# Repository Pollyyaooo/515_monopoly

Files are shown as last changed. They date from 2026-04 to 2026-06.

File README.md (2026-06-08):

# Smart Monopoly

A smart Monopoly system that automatically tracks board state and enforces rules, so players can focus on strategy and fun.

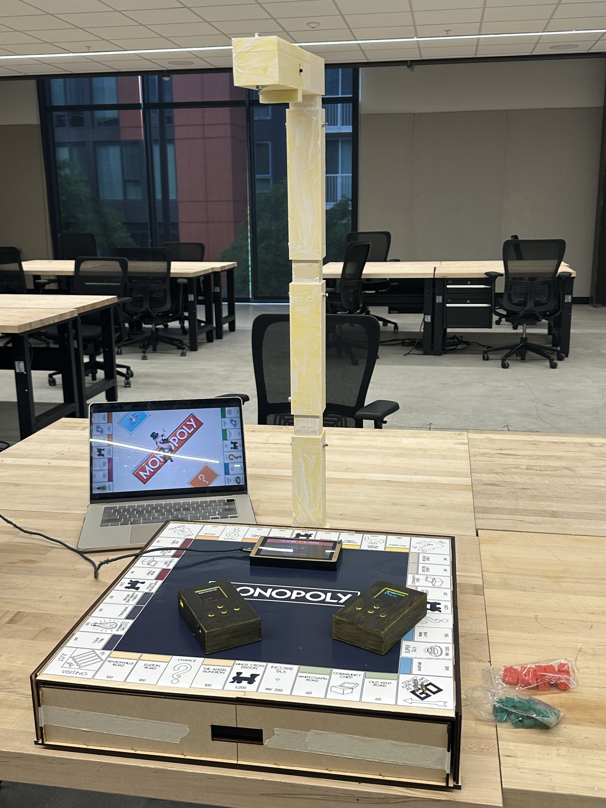
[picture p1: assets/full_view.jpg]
Full View

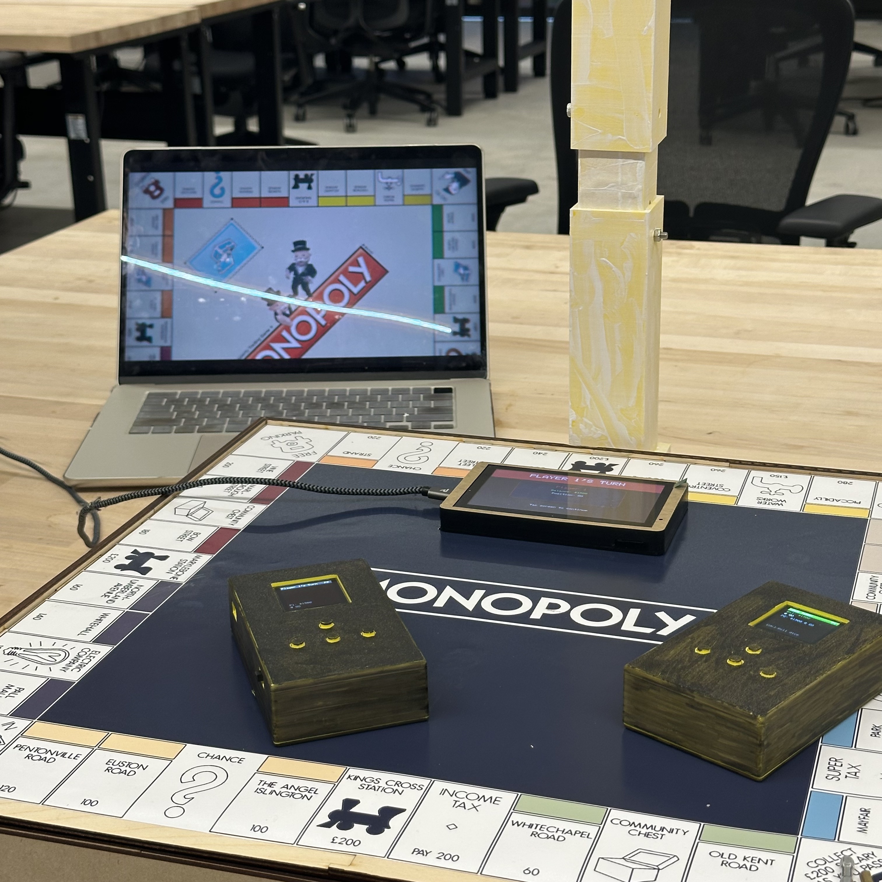
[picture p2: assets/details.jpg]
Details


## Demo Videos

| Scenario | Link |
|---|---|
| Vision detection — green house | [Watch](https://drive.google.com/file/d/1YYkAQqQGW3G5yaRUnQ6ajyW9RlyFcLrm/view?usp=drive_link) |
| Vision detection — red hotel | [Watch](https://drive.google.com/file/d/1fPO76GP8kFQUbU6NWimg8kV7IUoyudl7/view?usp=drive_link) |
| Auction | [Watch](https://drive.google.com/file/d/1G2KbDcnRxIF2fS2yyap2P3zmI8cTID51/view?usp=drive_link) |
| NFC payment | [Watch](https://drive.google.com/file/d/1PzwGUXprhIAtn__mJcu651hlFBT1dVyA/view?usp=drive_link) |

## System Overview

The system consists of three main components:

- **Vision subsystem** — Grove Vision AI V2 detects house/hotel placement on the board. An ESP32-C3 processes the raw coordinates into property-level data and transmits it to the central bank via ESP-NOW.
- **Central bank** — CrowPanel ESP32 5" manages all public game logic (dice rolls, chance/community cards, auctions, jail) and syncs state to both player devices via BLE. It also receives vision data and alerts players if houses are placed incorrectly.
- **Player devices (×2)** — Each device (XIAO ESP32-S3) has an OLED display, 4 buttons, and an NFC reader. Players use buttons to interact with the game and tap devices together for rent payments and auctions.

## Repository Structure

```
515_monopoly/
├── README.md
├── assets/
│   ├── full_view.jpg
│   └── details.jpg
├── software/
│   ├── README.md               # Code running instructions
│   ├── central_bank/           # CrowPanel ESP32 game logic & display
│   ├── player_card/            # XIAO ESP32-S3 player device firmware
│   ├── vision/                 # Grove Vision AI V2 + ESP32-C3 (ESP-NOW sender)
│   ├── central_display_test/   # Display UI testing
│   └── player_device_test/     # Player device testing
├── hardware/
│   ├── playbox+vision.f3z      # Fusion 360 enclosure & camera mount
│   ├── playbox_lasercut/       # SVG files for laser cutting
│   ├── player_card.f3z         # Fusion 360 player card enclosure
│   ├── player_card_pcb/        # PCB design files
│   ├── player_card_model/      # Player card 3D model files
│   └── vision_archi/           # Vision module hardware files
├── docs/
│   ├── milestone1.pdf
│   ├── milestone2.pdf
│   └── milestone3.pdf
└── test/                       # Early-stage hardware experiments (abandoned)
    ├── RFID test/
    ├── Hall Effect test/
    └── FSR test/
```

## Hardware

| Component | Role |
|---|---|
| Grove Vision AI V2 | House / hotel detection |
| ESP32-C3 | Coordinate processing & ESP-NOW transmission |
| CrowPanel ESP32 5" | Central bank — game logic & public display |
| XIAO ESP32-S3 (×2) | Player devices |
| OLED SSD1351 (×2) | Player display |
| NFC reader (×2) | Rent payment between players |

## Communication

| Link | Protocol |
|---|---|
| Grove Vision AI V2 → ESP32-C3 | UART |
| ESP32-C3 → CrowPanel | ESP-NOW |
| CrowPanel ↔ Player devices | BLE |
| Player device ↔ Player device | NFC |

## Team

- **Sienna** — All software (except vision model training)
- **Polly** — All hardware (enclosure, PCB, player card), vision model training & grid calibration

## Legacy Test Code

The `test/` folder contains early-stage hardware experiments (RFID, Hall Effect, FSR) that were explored during Milestone 1 but later abandoned in favour of the vision-based detection approach.

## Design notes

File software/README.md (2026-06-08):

# Monopoly Final — Smart Board Game System

A 2-player digital Monopoly system built with ESP32-S3 microcontrollers, featuring a central bank display and handheld player devices communicating over BLE.

## System Architecture

```
┌─────────────────────────┐       BLE        ┌─────────────────────────┐
│   Central Bank Display  │◄────────────────►│   Player Card (P1)      │
│   CrowPanel 5" 800×480  │                  │   XIAO ESP32S3          │
│   ESP32-S3 (game master)│       BLE        │   SSD1351 128×128 OLED  │
│                         │◄────────────────►│   PN532 NFC + 5 buttons │
└─────────────────────────┘                  ├─────────────────────────┤
                                             │   Player Card (P2)      │
                                             │   (same hardware)       │
                                             └─────────────────────────┘
```

## Hardware

| Component | Central Bank | Player Card |
|---|---|---|
| MCU | ESP32-S3 (CrowPanel 5") | Seeed XIAO ESP32S3 |
| Display | 5" IPS 800×480 (RGB parallel, LovyanGFX) | SSD1351 128×128 color OLED (SPI) |
| Input | Touchscreen (GT911) | 5 buttons (OK, LEFT, RIGHT, UP, DOWN) |
| NFC | — | PN532 (I2C) |
| Communication | BLE server (NimBLE) | BLE client (NimBLE) |

## Folder Structure

```
monopoly_final/
├── central_bank/          # Central bank display (PlatformIO project)
│   ├── platformio.ini
│   └── src/main.cpp       # Game master: state machine, dice, BLE server, UI
├── player_card/           # Player handheld device (PlatformIO project)
│   ├── platformio.ini     # Separate build envs for P1 and P2
│   └── src/main.cpp       # BLE client, OLED UI, NFC reader, button input
└── README.md
```

## Features

- **Full Monopoly rules**: 40-square UK board, property buying, rent, tax, Chance/Community Chest, jail, auctions
- **BLE communication**: Central bank acts as BLE server; player devices connect as clients
- **Dice rolling**: Dice animation on the central display, results broadcast to players
- **Property auctions**: When a player declines to buy, an auction starts with countdown timer
- **NFC payment**: Player-to-player rent payment confirmed via NFC tag tap
- **Ownership tracking**: Central bank tracks all property ownership; players can view their properties
- **Bankruptcy detection**: Automatic game-over when a player goes bankrupt

## BLE Protocol

- **Service UUID**: `0000AA01-0000-1000-8000-00805F9B34FB`
- **Notify characteristic** (central → players): `0000BB01-...`
- **Write characteristic** (players → central): `0000BB02-...`

Key messages:

| Direction | Message | Description |
|---|---|---|
| Central → Player | `TURN:{n}` | Player n's turn |
| Central → Player | `DICE:{sum}` | Dice result |
| Central → Player | `ACT:BUY:{name}:{price}` | Purchase option |
| Central → Player | `ACT:RENT:{amt}:{owner}` | Pay rent |
| Central → Player | `STATE:{p1pos}:{p1bal}:{p2pos}:{p2bal}` | Full state sync |
| Player → Central | `P{n}:ROLL` | Request dice roll |
| Player → Central | `P{n}:BUY` / `P{n}:SKIP` | Buy or skip property |

## Building & Flashing

Requires [PlatformIO](https://platformio.org/).

### Central Bank Display

```bash
cd central_bank
pio run -t upload
pio device monitor
```

### Player Cards

Flash Player 1:
```bash
cd player_card
pio run -e xiao_esp32s3_p1 -t upload
```

Flash Player 2:
```bash
cd player_card
pio run -e xiao_esp32s3_p2 -t upload
```

The player number is set via `-DPLAYER_NUM=1` or `-DPLAYER_NUM=2` in the build flags.

## Wiring (Player Card)

| OLED Pin | XIAO Pin | GPIO |
|---|---|---|
| DIN/MOSI | D10 | GPIO9 |
| CLK/SCK | D8 | GPIO7 |
| CS | D1 | GPIO1 |
| DC | D2 | GPIO2 |
| RST | D3 | GPIO3 |

PN532 NFC is connected via I2C (default SDA/SCL pins on XIAO ESP32S3).

## Team

- **Sienna** — board sensing, central display, game logic
- **Polly** — player device, BLE integration

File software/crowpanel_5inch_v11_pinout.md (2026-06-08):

# CrowPanel Advance 5.0" HMI ESP32-S3 — DIS02050A V1.1 引脚速查

> 来源：官方 GitHub `factory_sourcecode/V1.1/HMI-bigInch5/LovyanGFX_Driver.h`  
> **所有引脚已从官方代码确认，可直接使用**

---

## RGB 显示接口（16-bit 并行，Bus_RGB）

| 信号 | GPIO | 说明 |
|---|---|---|
| D0  | 21  | Blue[4] MSB |
| D1  | 47  | Blue[3] |
| D2  | 48  | Blue[2] |
| D3  | 45  | Blue[1] |
| D4  | 38  | Blue[0] LSB |
| D5  | 9 | Green[5] MSB |
| D6  | 10  | Green[4] |
| D7  | 11  | Green[3] |
| D8  | 12  | Green[2] |
| D9  | 13  | Green[1] |
| D10 | 14  | Green[0] LSB |
| D11 | 7 | Red[4] MSB |
| D12 | 17  | Red[3] |
| D13 | 18  | Red[2] |
| D14 | 3 | Red[1] |
| D15 | 46  | Red[0] LSB |
| DE (henable) | **42** | Data Enable |
| VSYNC | **41** | |
| HSYNC | **40** | |
| PCLK  | **39** | 21 MHz |

### 时序参数（官方值）

```
pclk_idle_high    = 1      ← 重要！不设会花屏
hsync_polarity    = 0
hsync_front_porch = 8
hsync_pulse_width = 4
hsync_back_porch  = 8
vsync_polarity    = 0
vsync_front_porch = 8
vsync_pulse_width = 4
vsync_back_porch  = 8
freq_write        = 21000000
```

---

## 触摸控制器（GT911）

| 参数 | 值 |
|---|----|
| 芯片 | GT911 |
| I2C 地址 | **0x5D** |
| SDA | **IO15** |
| SCL | **IO16** |
| INT | -1（无）|
| RST | -1（无）|
| I2C port | I2C_NUM_0 |
| 频率 | 400 kHz |

---

## STC8H1K28（背光 + Buzzer + 音频控制）

| 参数 | 值 |
|---|----|
| I2C 地址 | **0x30** |
| I2C 总线 | 与 GT911 共用，SDA=IO15, SCL=IO16 |

### 命令表

| 命令字节 | 功能 |
|---|---|
| `0x01` | 背光控制前导（先发此，再发亮度） |
| `0x05` | 背光最亮 |
| `0x10` | 背光最暗 |
| `0x15` | **Buzzer ON** |
| `0x16` | **Buzzer OFF** |
| `0x17` | 音频 Unmute |
| `0x18` | 音频 Mute |

### 背光控制代码

```cpp
Wire.begin(15, 16);          // 初始化 I2C

// 设置亮度（先发 0x01，再发亮度值）
Wire.beginTransmission(0x30);
Wire.write(0x01);
Wire.endTransmission();
delay(5);
Wire.beginTransmission(0x30);
Wire.write(0x05);  // 最亮
Wire.endTransmission();

// Buzzer
Wire.beginTransmission(0x30);
Wire.write(0x15);  // ON
Wire.endTransmission();
delay(100);
Wire.beginTransmission(0x30);
Wire.write(0x16);  // OFF
Wire.endTransmission();
```

> ⚠️ **没有背光 GPIO** — V1.1 完全通过 I2C 控制，代码中不需要 `setBrightness()` 或任何 `Light_PWM`

---

## RTC（BM8563）

| 参数 | 值 |
|---|----|
| I2C 地址 | **0x51** |
| SDA | IO15 |
| SCL | IO16 |

> 与 GT911（0x5D）和 STC8H1K28（0x30）共用同一 I2C 总线

---

## 其他接口引脚

| 功能 | GPIO |
|---|---|
| UART0 TX | IO43 |
| UART0 RX | IO44 |
| UART1 TX | IO20 |
| UART1 RX | IO19 |
| SPK LRCLK | IO6 |
| SPK BCLK | IO5 |
| SPK SDIN | IO4 |
| MIC SD | IO20 |
| MIC WS | IO2 |
| MIC CLK | IO19 |
| SD MOSI | IO6 |
| SD MISO | IO4 |
| SD CLK | IO5 |

---

## PSRAM 启用

官方代码中启用了 PSRAM（`use_psram = 1`），platformio.ini 需要：

```ini
board_build.arduino.memory_type = qio_opi
build_flags = -DBOARD_HAS_PSRAM
```

---

## 官方 GitHub

`https://github.com/Elecrow-RD/CrowPanel-Advance-5-HMI-ESP32-S3-AI-Powered-IPS-Touch-Screen-800x480`

关键文件：`factory_sourcecode/V1.1/HMI-bigInch5/LovyanGFX_Driver.h`

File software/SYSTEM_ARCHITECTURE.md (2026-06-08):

# Monopoly Physical Game System — 系统架构文档

> **版本:** v1.0 · **日期:** 2026-05-08  
> **项目:** UW MSTI 515 · Phygital Monopoly

---

## 1. 系统总览

本系统将经典大富翁拆分为两类设备，职责清晰：

| 设备 | 硬件 | 职责 |
|---|---|---|
| **Central Display（公共屏幕）** | CrowPanel ESP32-S3 5" (DIS02050A) | 讲故事、投骰子动画、公共事件、回合广播 |
| **Player Device（玩家设备）** | Seeed XIAO ESP32S3 + SSD1351 128×128 OLED + PN532 | 个人资产、个人决策、支付确认、NFC 位置扫描 |

通信方式：**Bluetooth Low Energy (BLE)**  
拓扑：Central Display 作为 **BLE Central（Server）**，最多 4 台 Player Device 作为 **BLE Peripherals（Clients）**

```
┌──────────────────────────────────────────────────────────────────┐
│                     CrowPanel 5" (Central Display)               │
│  ESP32-S3 WROOM-1 · 800×480 Touch · Buzzer · Speaker            │
│                                                                  │
│  ┌─────────────┐  ┌──────────────┐  ┌────────────────────────┐  │
│  │ Game Engine │  │  BLE Central │  │   Display / Animation  │  │
│  │  (Master)   │←→│  (4 slots)   │  │  Dice · Cards · Events │  │
│  └─────────────┘  └──────┬───────┘  └────────────────────────┘  │
│                           │ BLE                                   │
└───────────────────────────┼──────────────────────────────────────┘
                            │
         ┌──────────────────┼──────────────────┐
         │                  │                  │
  ┌──────┴──────┐   ┌──────┴──────┐   ┌──────┴──────┐
  │  Player 1   │   │  Player 2   │   │  Player 3/4 │
  │ XIAO ESP32S3│   │ XIAO ESP32S3│   │ XIAO ESP32S3│
  │ OLED + NFC  │   │ OLED + NFC  │   │ OLED + NFC  │
  └─────────────┘   └─────────────┘   └─────────────┘
```

---

## 2. 硬件规格

### 2.1 Central Display — CrowPanel ESP32-S3 5"

| 参数 | 值 |
|---|----|
| SKU | DIS02050A V1.1 |
| MCU | ESP32-S3 WROOM-1 |
| 屏幕 | 5.0" TFT，800×480，电容触摸 |
| 接口 | UART0/1-IN/OUT · I2C-OUT · USB-5V-IN |
| 音频 | 板载 Buzzer + Speaker (SPK 接口) |
| 存储 | TF Card slot |
| 电源 | USB-5V-IN / BAT |
| BLE | ESP32-S3 内置 BLE 5.0 |

**推荐开发框架：** Arduino (PlatformIO) + LVGL 8.x（UI 动画）

### 2.2 Player Device — Seeed XIAO ESP32S3

| 参数 | 值 |
|---|----|
| MCU | ESP32-S3 |
| 显示 | SSD1351 128×128 RGB OLED (SPI) |
| NFC | PN532（I2C 模式） |
| 输入 | 5× 触觉按钮（UP / DOWN / LEFT / RIGHT / OK） |
| BLE | ESP32-S3 内置 BLE 5.0 |

---

## 3. BLE 通信协议

### 3.1 拓扑与连接

- Central Display 开启 **BLE Server**，广播服务 UUID。
- 每台 Player Device 启动后扫描并连接 Central，注册自己的 Player ID（0~3）。
- 最多同时 4 条 BLE 连接。

### 3.2 GATT 服务定义

```
Service UUID: 0xAA01  (Monopoly Game Service)
│
├── Characteristic 0xBB01  [NOTIFY | WRITE]
│   名称: Game Event (Central → Players)
│   方向: Central 广播给所有 Player
│   载荷: JSON 或固定字节包（见 3.3）
│
├── Characteristic 0xBB02  [WRITE]
│   名称: Player Action (Player → Central)
│   方向: Player Device 上报动作
│   载荷: 固定字节包
│
└── Characteristic 0xBB03  [READ]
    名称: Game State Snapshot
    方向: Player 可随时读取完整游戏状态
    载荷: 压缩状态包
```

### 3.3 消息包格式

#### Central → Player（Game Event Packet）

```
[1B] msg_type  | 消息类型（见下表）
[1B] player_id | 目标 player（0xFF = 广播全体）
[2B] payload_a | 主要参数
[2B] payload_b | 次要参数
[1B] checksum  | XOR 校验
```

| msg_type | 含义 | payload_a | payload_b |
|---|---|---|---|
| `0x01` | YOUR_TURN | player_id | — |
| `0x02` | DICE_RESULT | die1 (1-6) | die2 (1-6) |
| `0x03` | MOVE_TO | square_index | — |
| `0x04` | CHANCE_CARD | card_id | — |
| `0x05` | COMMUNITY_CARD | card_id | — |
| `0x06` | PAY_REQUEST | amount (uint16) | recipient_id |
| `0x07` | COLLECT | amount (uint16) | source (0=bank) |
| `0x08` | GO_TO_JAIL | — | — |
| `0x09` | GAME_OVER | winner_id | — |
| `0x0A` | SYNC_BALANCE | balance (uint16) | — |
| `0x0B` | PROPERTY_UPDATE | square_index | owner_id |

#### Player → Central（Player Action Packet）

```
[1B] msg_type  | 动作类型
[1B] player_id | 发送方
[2B] payload_a |
[2B] payload_b |
[1B] checksum  |
```

| msg_type | 含义 | payload_a | payload_b |
|---|---|---|---|
| `0x81` | ROLL_DICE | — | — |
| `0x82` | BUY_PROPERTY | square_index | — |
| `0x83` | PAY_CONFIRM | amount | recipient_id |
| `0x84` | PAY_REJECT | — | — |
| `0x85` | USE_CARD | card_id | — |
| `0x86` | NFC_SCANNED | square_index | — |
| `0x87` | END_TURN | — | — |
| `0x88` | MORTGAGE | square_index | — |

---

## 4. Game Engine（运行在 Central Display）

Central Display 是游戏的**唯一权威状态机**，所有 Player Device 只展示结果、等待指令。

### 4.1 状态机

```
WAITING_FOR_PLAYERS
      │ 4 players connected
      ▼
   GAME_START
      │ broadcast turn order
      ▼
┌─► PLAYER_TURN_START
│     │ broadcast YOUR_TURN → player_id
│     ▼
│   WAITING_ROLL
│     │ receive ROLL_DICE from current player
│     ▼
│   ROLLING_DICE ──── 播放骰子动画（Central屏幕）
│     │ animation done, compute result
│     │ broadcast DICE_RESULT
│     ▼
│   MOVING_PLAYER ─── 广播 MOVE_TO
│     │
│     ▼
│   RESOLVE_SQUARE ───────────────────────────────────────────────┐
│     │ SQ_PROPERTY  → 广播 PAY_REQUEST 或 BUY 选项              │
│     │ SQ_CHANCE    → 抽卡，广播 CHANCE_CARD + 执行效果         │
│     │ SQ_COMMUNITY → 抽卡，广播 COMMUNITY_CARD + 执行效果      │
│     │ SQ_TAX       → 广播 PAY_REQUEST (bank)                   │
│     │ SQ_GO_JAIL   → 广播 GO_TO_JAIL                           │
│     │ SQ_SPECIAL   → 无动作 / Collect $200                     │
│     │                                                           │
│     ▼                                                           │
│   WAITING_PLAYER_ACTION ←──────────────────────────────────────┘
│     │ receive PAY_CONFIRM / BUY / END_TURN
│     │ update GameState
│     │ broadcast SYNC_BALANCE to affected players
│     ▼
│   CHECK_BANKRUPTCY ─── 检查是否有玩家破产
│     │ if bankrupt → remove player
│     │ if 1 player left → GAME_OVER
│     ▼
└─── TURN_END ─── next player
```

### 4.2 GameState 数据结构（Central 持有）

```cpp
struct GameState {
  Player  players[4];       // 所有玩家状态
  Square  board[40];        // 完整 40 格棋盘
  int     currentTurnIdx;   // 当前回合玩家
  int     totalPlayers;     // 在线玩家数
  int     chanceDeck[16];   // Chance 牌堆
  int     communityDeck[16];// Community Chest 牌堆
  int     chanceTop;        // 当前抽牌指针
  int     communityTop;
  bool    doublesRolled;    // 是否连续骰到 doubles
  int     doublesCount;
};
```

---

## 5. Central Display — UI 模块

### 5.1 屏幕页面划分

```
┌─────────────────────────────────────────┐
│  CrowPanel 5"  800×480                  │
│                                         │
│  主要页面（全屏）：                      │
│  ┌──────────────────────────────────┐   │
│  │ IDLE / WAITING    等待玩家连接   │   │
│  ├──────────────────────────────────┤   │
│  │ DICE ROLL SCREEN  投骰子动画     │   │
│  ├──────────────────────────────────┤   │
│  │ EVENT SCREEN      公共事件通知   │   │
│  ├──────────────────────────────────┤   │
│  │ CARD DRAW         Chance/Community│  │
│  ├──────────────────────────────────┤   │
│  │ BOARD OVERVIEW    棋盘全览（可选）│  │
│  └──────────────────────────────────┘   │
└─────────────────────────────────────────┘
```

### 5.2 骰子动画（Dice Roll Screen）

- 收到 `ROLL_DICE` 请求后触发
- 播放 **随机旋转骰子精灵图动画**（LVGL `lv_animimg` 或帧循环）
- 动画时长：1.5~2 秒，渐慢停止
- 停止后显示最终骰子面值（大字，带声效 Buzzer）
- 发送 `DICE_RESULT` BLE 广播

**实现方案：**
```
TF Card 存储骰子帧图片（BMP/PNG）
→ LVGL lv_img / lv_animimg 逐帧播放
→ 结束帧 = 实际 RNG 结果
```

### 5.3 公共事件屏（Event Screen）

显示触发事件，保持 3~5 秒后自动进入下一状态：

| 事件 | 显示内容 |
|---|---|
| 回合开始 | "🎲 Alice's Turn!" + 玩家颜色背景 |
| 移动完成 | "Alice → Park Place" |
| 抽 Chance 牌 | 大字显示牌面内容 + 图标 |
| 抽 Community 牌 | 大字显示牌面内容 + 图标 |
| 支付发生 | "Alice pays Bob $50" |
| 入狱 | "🔒 Alice goes to Jail!" |
| 通过 Go | "Alice collects $200!" |
| 破产 | "Dave is bankrupt! 💸" |
| 游戏结束 | "Alice WINS! 🏆" |

### 5.4 抽卡画面（Card Draw Screen）

- 动画：卡片从牌堆飞出，翻转展示正面
- 正面显示：卡牌名称 + 描述文字 + 效果图标
- 保持显示直到触摸屏或收到 `END_TURN`

---

## 6. Player Device — UI 模块（已有基础版）

### 6.1 现有页面（保持不变）

| 页面 | 内容 |
|---|---|
| PAGE_HOME | 玩家名、余额、位置、道具/卡牌数量 |
| PAGE_ACTION | 当前格子可执行动作（买/付租金/税） |
| PAGE_PROPERTIES | 持有地产列表（含房屋图标） |
| PAGE_CARDS | 持有卡牌列表 |
| PAGE_NFC_SCAN | NFC 扫描提示 |

### 6.2 新增页面（BLE 接入后）

| 页面 | 触发时机 | 内容 |
|---|---|---|
| PAGE_WAIT_TURN | 非当前玩家 | "Bob's turn..." + 当前回合进度 |
| PAGE_PAY_CONFIRM | 收到 `PAY_REQUEST` | "Pay $50 to Bob? OK/Cancel" |
| PAGE_CARD_RECEIVED | 收到 Chance/Community 结果 | 显示抽到的牌效果 |
| PAGE_BANKRUPT | 余额 < 0 | "You are bankrupt!" |

### 6.3 BLE 接入流程（Player Device 侧）

```
setup():
  1. 扫描 BLE，连接 UUID=0xAA01 的 Central
  2. 订阅 Characteristic 0xBB01 (NOTIFY)
  3. 发送注册包：player_id = 用户选择的颜色/编号

loop():
  - 监听 BLE NOTIFY 回调 → 解析 Game Event → 更新本地状态 → 刷新 OLED
  - 处理按钮 → 构造 Player Action 包 → BLE WRITE 到 0xBB02
  - NFC 扫描 → 发送 NFC_SCANNED 包 → 等待 Central 下发 MOVE_TO
```

---

## 7. 开发分工与文件结构

```
monopoly_final/
│
├── central_display/              # CrowPanel 5" 固件
│   ├── platformio.ini
│   └── src/
│       ├── main.cpp              # setup / loop
│       ├── game_engine.h/cpp     # GameState + 状态机
│       ├── ble_central.h/cpp     # BLE Server / 4连接管理
│       ├── ui_dice.h/cpp         # 骰子动画
│       ├── ui_event.h/cpp        # 公共事件屏
│       ├── ui_card.h/cpp         # 抽卡画面
│       └── cards_data.h          # 所有 Chance / Community 牌内容
│
├── player_device/                # XIAO ESP32S3 固件（含现有代码）
│   ├── platformio.ini
│   └── src/
│       ├── main.cpp              # setup / loop（扩展现有版本）
│       ├── ble_client.h/cpp      # BLE Peripheral / NOTIFY 处理
│       ├── game_state.h/cpp      # 本地 GameState 镜像
│       ├── ui_pages.h/cpp        # 所有页面绘制（现有 + 新增）
│       └── nfc_handler.h/cpp     # PN532 扫描逻辑
│
├── shared/                       # 两端共用定义
│   └── protocol.h                # BLE UUID / 消息包结构 / 枚举
│
└── SYSTEM_ARCHITECTURE.md        # 本文档
```

---

## 8. 开发阶段规划

### Phase 1：BLE 连接基础（无游戏逻辑）
- [ ] Central：BLE Server 广播 + 接受 4 连接
- [ ] Player：BLE Client 扫描连接 + 发送心跳
- [ ] 验证：4 台设备同时连接，收发测试包

### Phase 2：骰子 + 回合广播
- [ ] Central：骰子动画（LVGL）+ RNG + 广播 DICE_RESULT
- [ ] Central：YOUR_TURN 广播 + 事件屏显示
- [ ] Player：接收 YOUR_TURN → 高亮显示 → 按 OK 发送 ROLL_DICE

### Phase 3：NFC 位置 + 格子解析
- [ ] Player：PN532 扫描 → 发送 NFC_SCANNED
- [ ] Central：接收 NFC_SCANNED → 更新 position → 广播 MOVE_TO + 解析格子事件

### Phase 4：支付 + 资产管理
- [ ] Central：PAY_REQUEST 定向发送 + 等待 PAY_CONFIRM
- [ ] Player：PAY_CONFIRM 页面 + BLE 回复
- [ ] Central：SYNC_BALANCE 广播 → Player 更新余额显示

### Phase 5：Chance / Community 牌
- [ ] Central：抽卡动画 + 牌效果执行 + 广播
- [ ] Player：接收 CARD_RECEIVED → 显示卡牌内容页面

### Phase 6：整体测试 + 音效
- [ ] CrowPanel Buzzer：骰子 / 收钱 / 入狱 音效
- [ ] 端到端完整游戏流程测试

---

## 9. 关键技术选型说明

| 决策 | 选择 | 原因 |
|---|---|---|
| 通信协议 | BLE（非 WiFi） | 无需路由器，现场部署简单；ESP32-S3 原生支持 |
| Central 为 Server | 是 | 状态权威在 Central，避免多端同步冲突 |
| UI 框架（Central）| LVGL 8.x | CrowPanel 官方支持；动画能力强（animimg、过渡效果） |
| UI 框架（Player）| Adafruit GFX | 已有稳定基础代码，资源占用低 |
| NFC → 位置映射 | Player 本地查表 + 上报 index | 减少 BLE 传输量；Central 收到 index 即可 |
| 游戏状态存储 | Central 单一权威 | Player Device 只保存本地镜像，以 Central 为准 |

---

## 10. BLE 实现参考（Arduino NimBLE）

两端均使用 **NimBLE-Arduino** 库（PlatformIO 依赖：`h2zero/NimBLE-Arduino`），资源占用比官方 ESP-IDF BLE 栈小约 50%。

```cpp
// platformio.ini 公共依赖
[env]
lib_deps =
  h2zero/NimBLE-Arduino @ ^1.4.1
  lvgl/lvgl @ ^8.3.0          ; Central only
  adafruit/Adafruit GFX Library
  adafruit/Adafruit SSD1351 library
  adafruit/Adafruit PN532     ; Player only
```

---

*文档由 Claude Code 辅助生成，基于现有 player_device_test 代码与 CrowPanel DIS02050A 硬件规格。*

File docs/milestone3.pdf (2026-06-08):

# Morden MONOPOLY

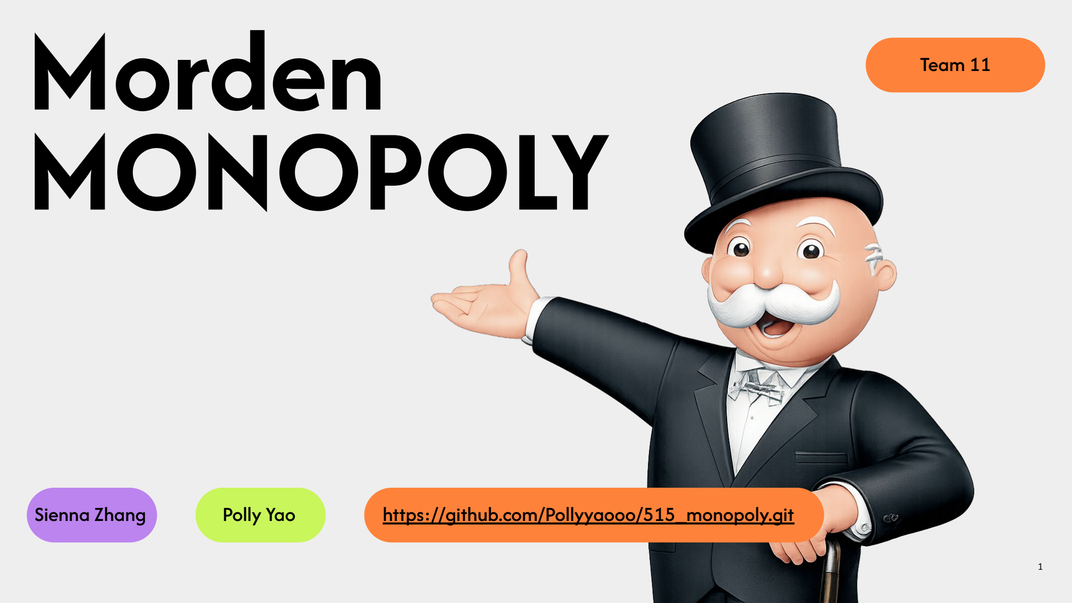
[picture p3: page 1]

## Team 11

Sienna Zhang | Polly Yao | https://github.com/Pollyyaooo/515_monopoly.git

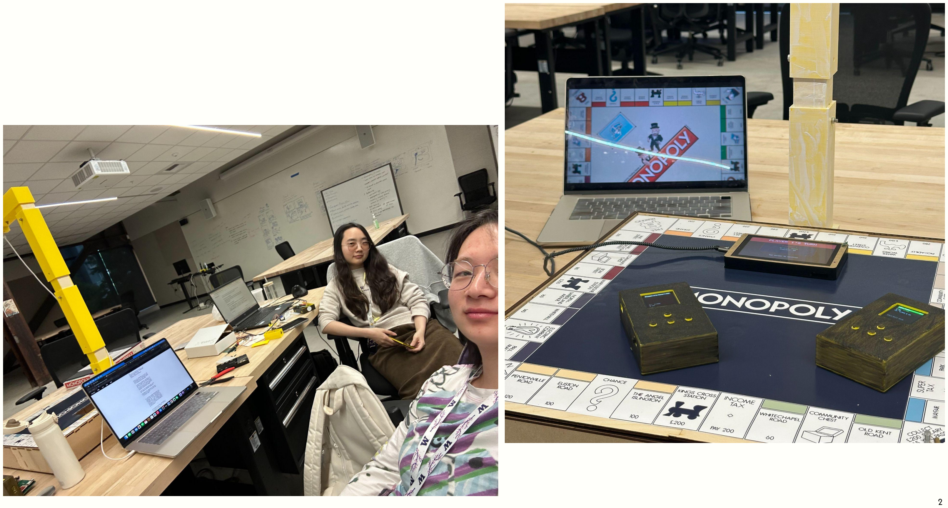
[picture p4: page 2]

“

# How might we reduce the administrative burden of tracking game state and enforcing rules in Monopoly, so that all players can focus on strategy and fun?

# Why we want…

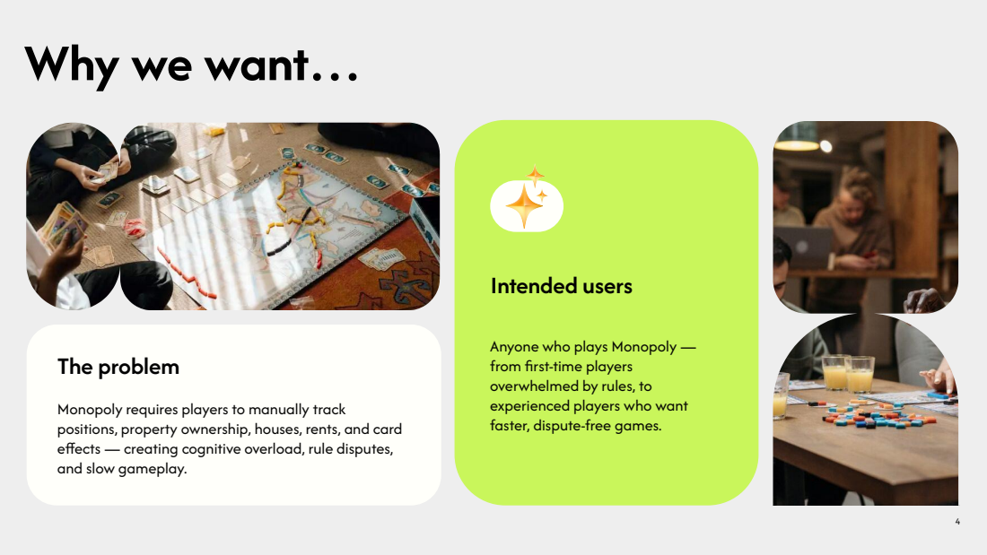
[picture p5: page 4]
Intended users; The problem

Anyone who plays Monopoly —
from first-time players
overwhelmed by rules, to
experienced players who want
faster, dispute-free games.

Monopoly requires players to manually track
positions, property ownership, houses, rents, and card
effects — creating cognitive overload, rule disputes,
and slow gameplay.

# Solution

# A smart Monopoly system that automatically tracks board state and enforces rules, so

players never have to.

# Board Intelligence

## The physical board is enhanced with sensors to automatically detect and track:

## - Player token positions (who is where) - Property ownership status - Number and color of houses built on each property

# Rules Intelligence

## Game information is processed and displayed in real time across two interfaces: - A Central Bank screen (public display) — shows card draws, rent calculations, property transactions… - Individual player devices (private display) —

shows personal balance, rent owed/collected, player-to-player transfers..

# Architecture 2

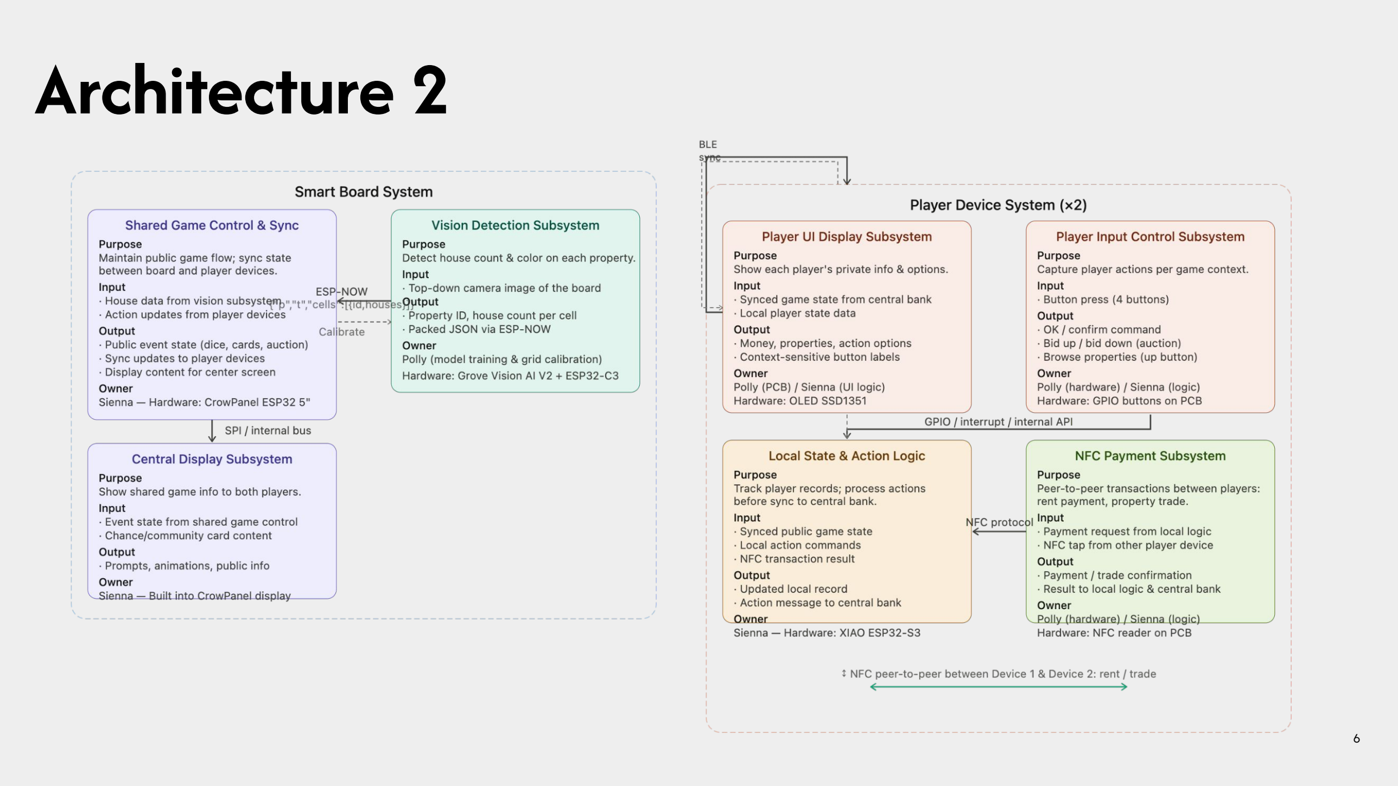
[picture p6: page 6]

# Optimization 1 - Enclosure & Camera Mount Stability

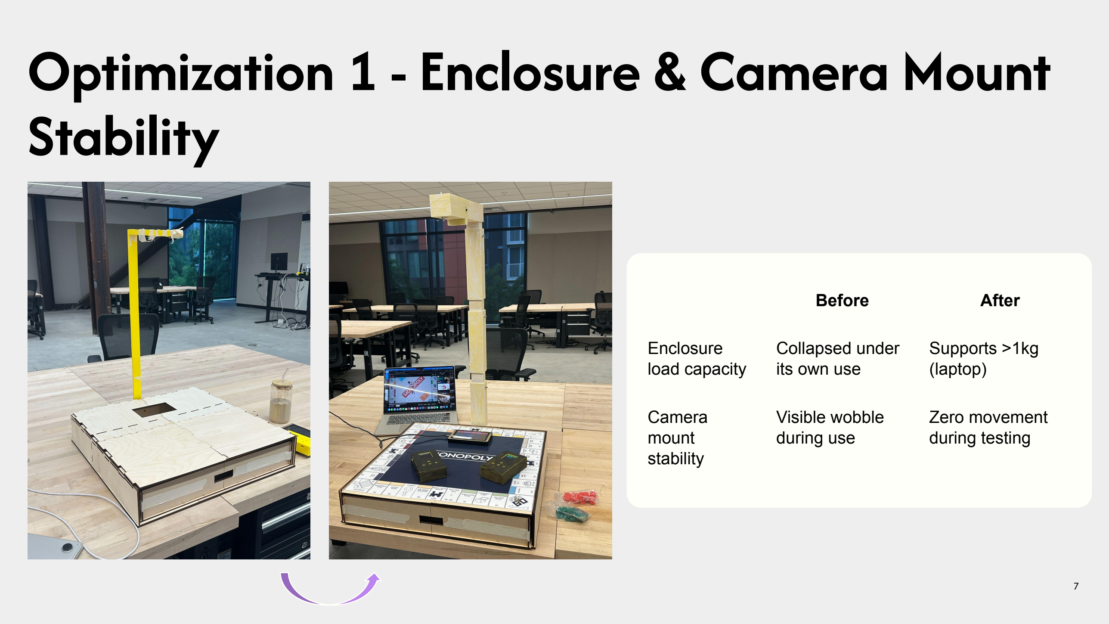
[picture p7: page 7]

Before | After

Enclosure
load capacity
Collapsed under its own use | Supports >1kg (laptop)

Camera
mount
stability
Visible wobble during use | Zero movement during testing

# Optimization 2 - Central Display UI

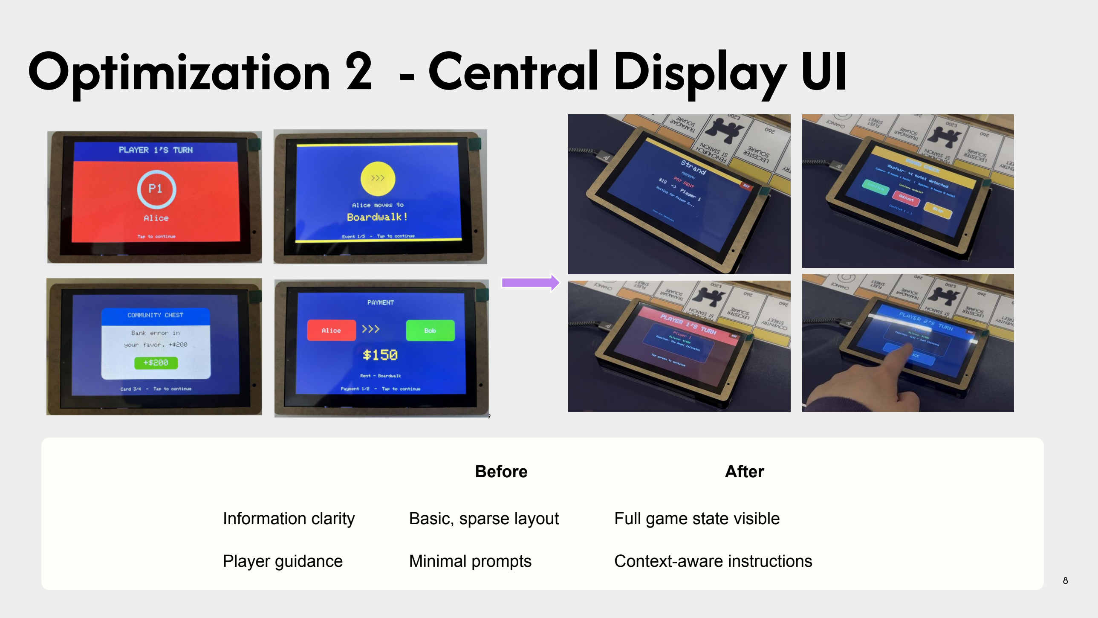
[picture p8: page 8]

| Before | After
Information clarity | Basic, sparse layout | Full game state visible
Player guidance | Minimal prompts | Context-aware instructions

# Optimization 3

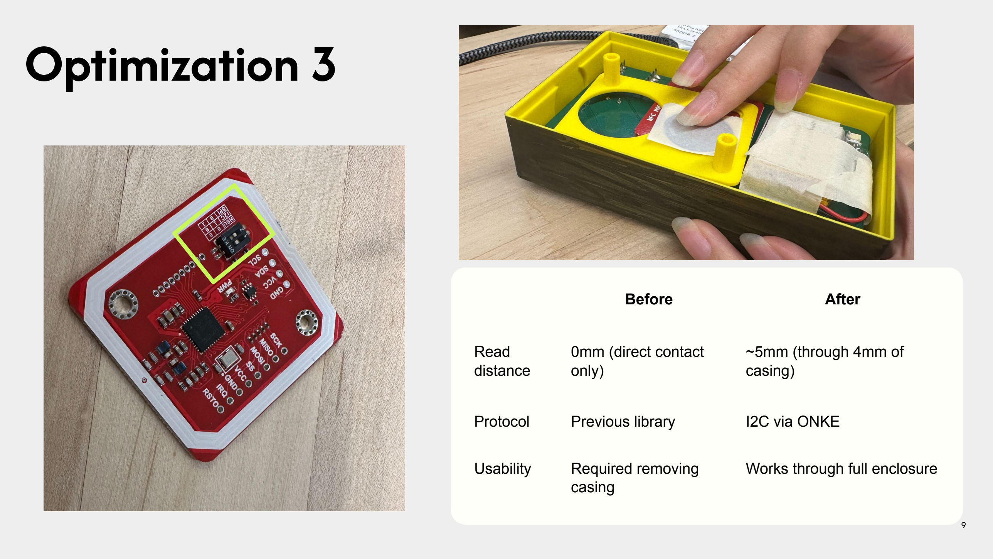
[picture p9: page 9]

Before | After

Read
distance

0mm (direct contact
only)

~5mm (through 4mm of
casing)
Protocol | Previous library | I2C via ONKE
Usability | Required removing casing | Works through full enclosure

# Readiness - NFC vs auction

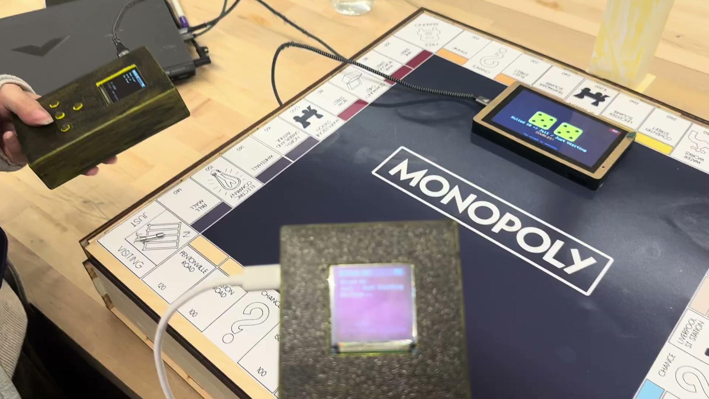
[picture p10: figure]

Condition 1: NFC-based rent payment When a player lands on an opponent's property, the system triggers a rent payment flow. The paying player taps their device to the receiving player's NFC reader to complete the transaction, with the updated balance automatically synced to the central bank.

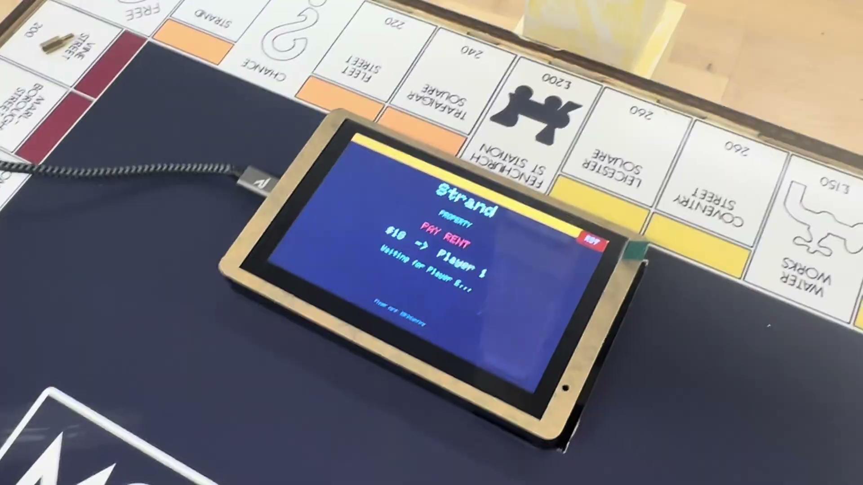
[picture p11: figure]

Condition 2: Button-based auction When a property is not purchased by the landing player, an auction is triggered on the central display. Both players use the left/right buttons on their devices to raise or lower their bids, and confirm with the center button. The highest confirmed bid wins the property.

# Readiness - house vs hotel

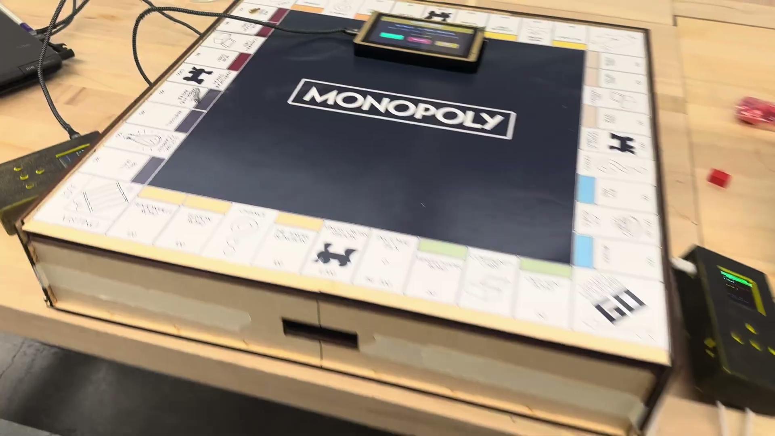
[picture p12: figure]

Condition 1: Incorrect green house placement A property is deliberately set up with an incorrect number of green houses on the board. The camera subsystem detects the mismatch between the physical board state and the expected game state, triggering a visual alert on the central display to prompt the players to correct the placement.

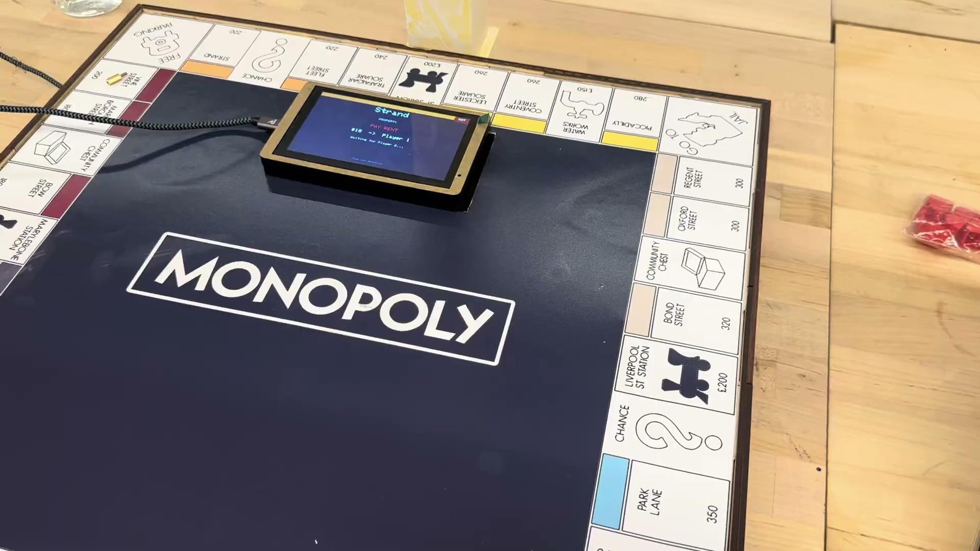
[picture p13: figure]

Condition 2: Incorrect red hotel placement The same detection flow is tested with red hotels, which differ in both color and shape from green houses. The camera subsystem successfully identifies the incorrect number of hotels and triggers a corresponding alert on the central display, demonstrating that the vision model generalizes across both building types.

# Budget update

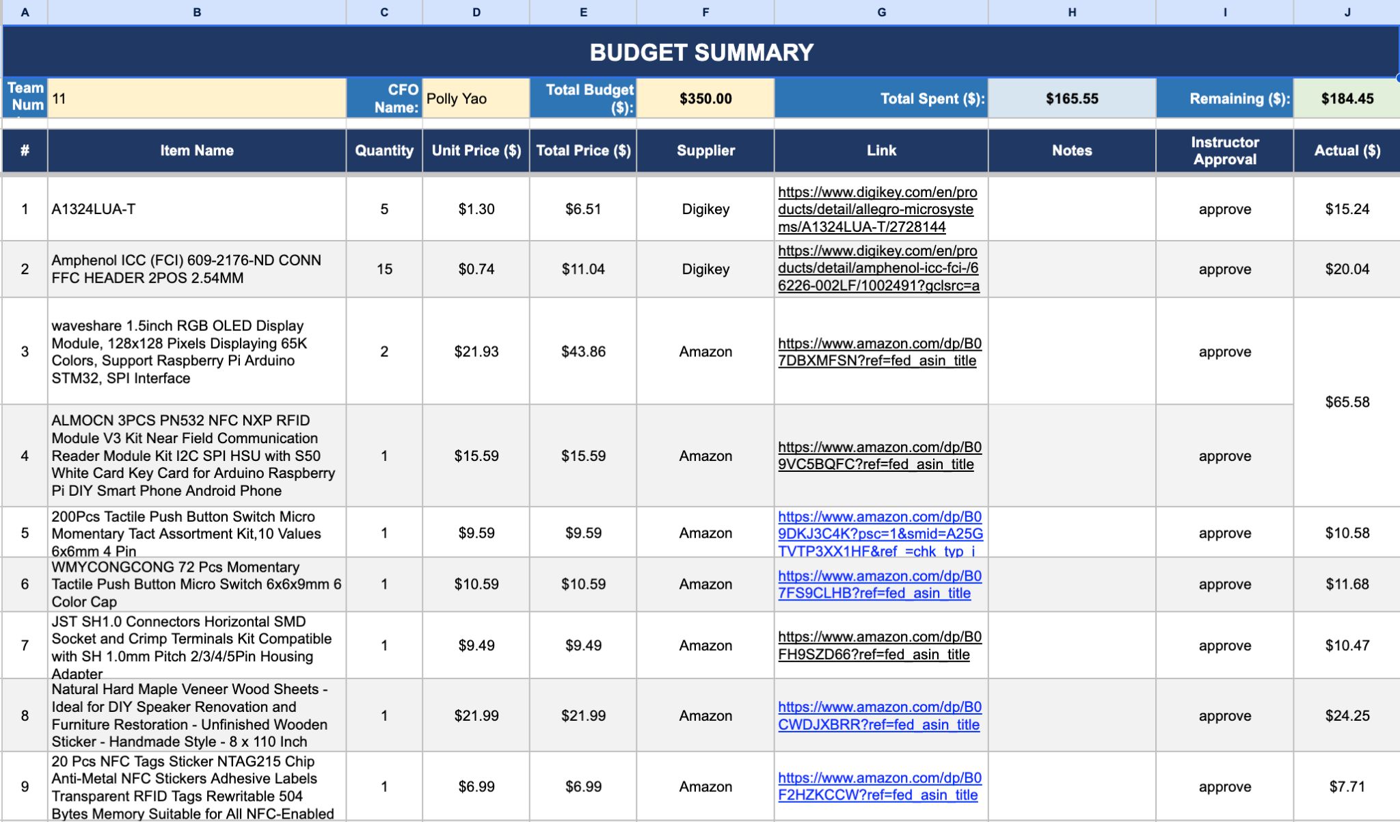
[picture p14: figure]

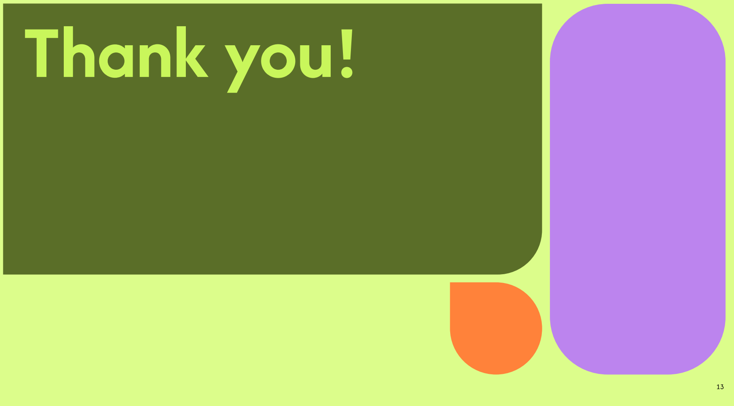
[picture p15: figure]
Thank you!

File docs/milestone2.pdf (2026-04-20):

# Morden MONOPOLY


Team 11

Sienna Zhang | Polly Yao | https://github.com/Pollyyaooo/515_monopoly.git

“

# How might we reduce the administrative burden of tracking game state and enforcing rules in Monopoly, so that all players can focus on strategy and fun?

# Why we want…

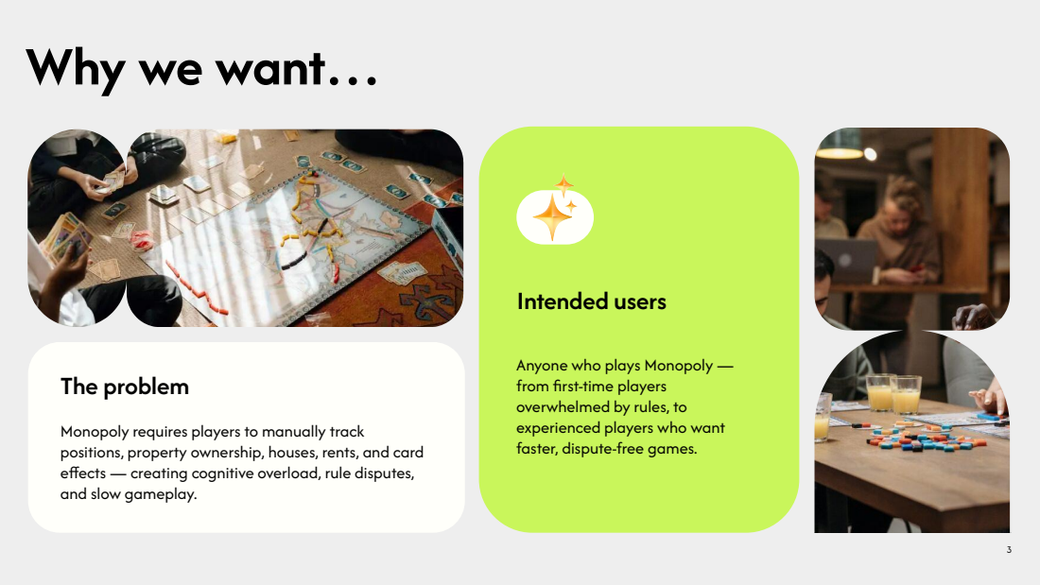
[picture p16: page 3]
Intended users; The problem

Anyone who plays Monopoly —
from first-time players
overwhelmed by rules, to
experienced players who want
faster, dispute-free games.

Monopoly requires players to manually track
positions, property ownership, houses, rents, and card
effects — creating cognitive overload, rule disputes,
and slow gameplay.

# Solution

## A smart Monopoly system that automatically tracks board state and enforces rules, so

players never have to.

## Board Intelligence

The physical board is enhanced with sensors to automatically detect and track:

- Player token positions (who is where)
- Property ownership status
- Number and color of houses built on each property

## Rules Intelligence

Game information is processed and displayed in real time across two interfaces:
- A Central Bank screen (public display) — shows card draws, rent calculations, property transactions…
- Individual player devices (private display) — shows personal balance, rent owed/collected, player-to-player transfers..

# Architecture 2

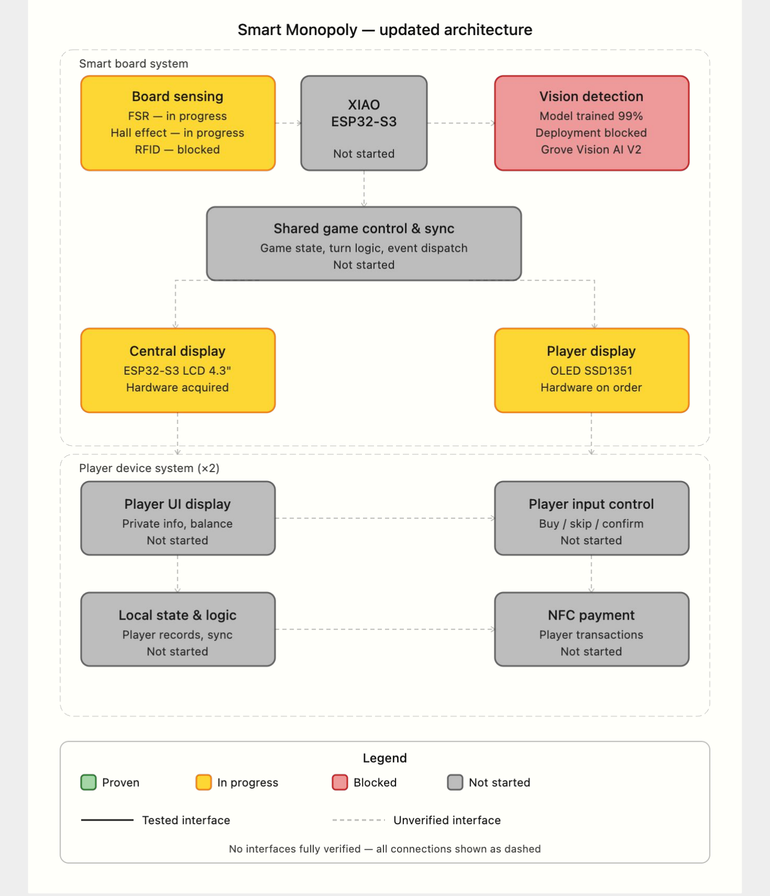
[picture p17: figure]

# Validation 1 - RFID

We tested the RFID system with multiple tags and readers. A single RFID reader can successfully detect two tags simultaneously. However, when two RFID readers are placed too close to each other(<2cm), neither of them can detect any tags. This indicates signal interference between readers.

Prototype1_RFID_board_cover.MOV (https://drive.google.com/file/d/1QlqDFTdXGZJRtCotWlre7GudlHrpasP2/view?usp=drive_link)

Prototype1_RFID_2tags.MOV (https://drive.google.com/file/d/1kOY5OB9miVhctIHM5gq4FT3wfoS5CscW/view?usp=drive_link)

Prototype1_RFID_1tag.MOV (https://drive.google.com/file/d/16mHRYZAYOvNZ8MaQr5gDhi9f_tx55qLL/view?usp=drive_link)

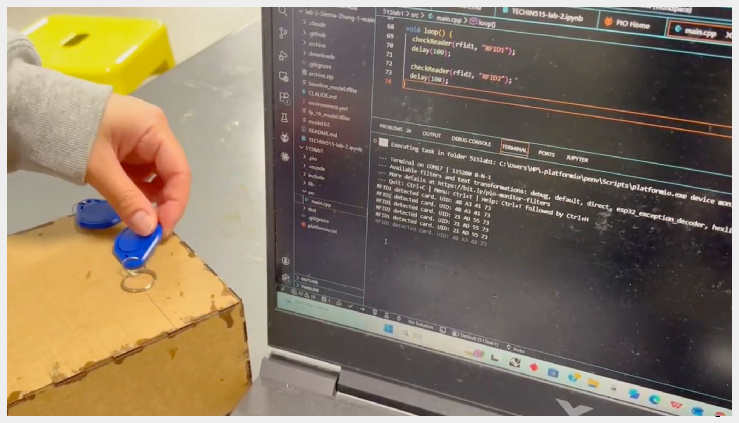
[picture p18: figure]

# Validation 2 - FSR Sensor

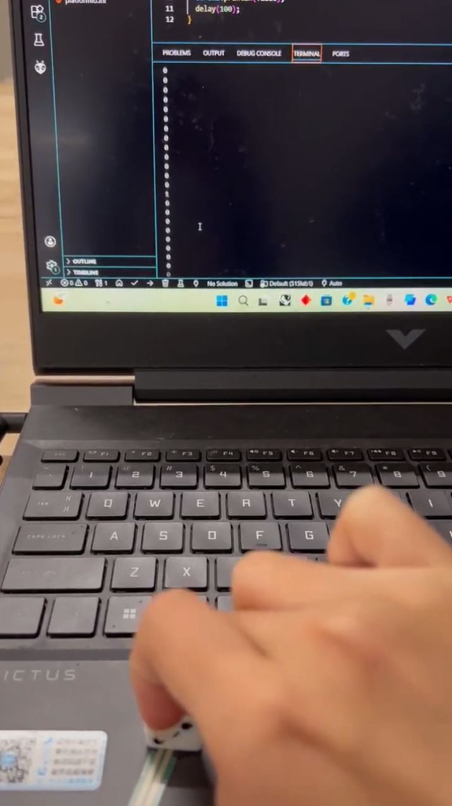
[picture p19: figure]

We tested the force-sensitive resistor (FSR) for detecting object placement. We found that the contact area must be smaller than the circular sensing region of the FSR; otherwise, the sensor fails to detect pressure effectively. Additionally, very light objects are not reliably detected. Based on this, we are considering adding weights inside the game pieces to ensure sufficient pressure.

Prototype1_FSR.mp4 (https://drive.google.com/file/d/1zIbYLgiZHWypi_CHvMiKM61M6fQsIUk4/view?usp=drive_link)

# Validation 3 - Vision

We mounted the OV5647-62 camera on Grove Vision AI V2 and determined via live preview that a mounting height of approximately 65cm is required to fully capture the 50×50cm Monopoly board. We collected 67 annotated images of red and green houses, augmented to 161 images, and trained a YOLOv11 object detection model achieving mAP@50 = 99.0%, Precision = 99.9%, Recall = 98.7%. Qualitative webcam testing confirmed reliable color distinction between red and green houses across different board positions. However, deployment to Grove Vision AI V2 requires int8_vela.tflite format conversion, which has not yet been successfully completed.

https://app.roboflow.com/yitongs-workspace/monopoly-houses/models/monopoly-houses/1 (https://app.roboflow.com/yitongs-workspace/monopoly-houses/models/monopoly-houses/1)

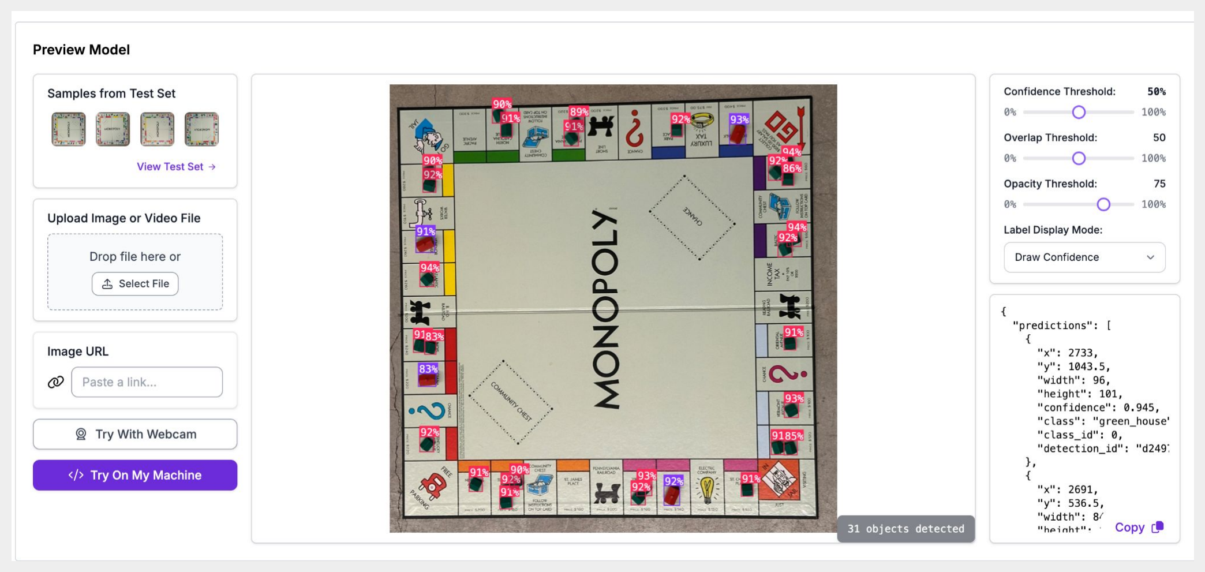
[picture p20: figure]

# Budget update

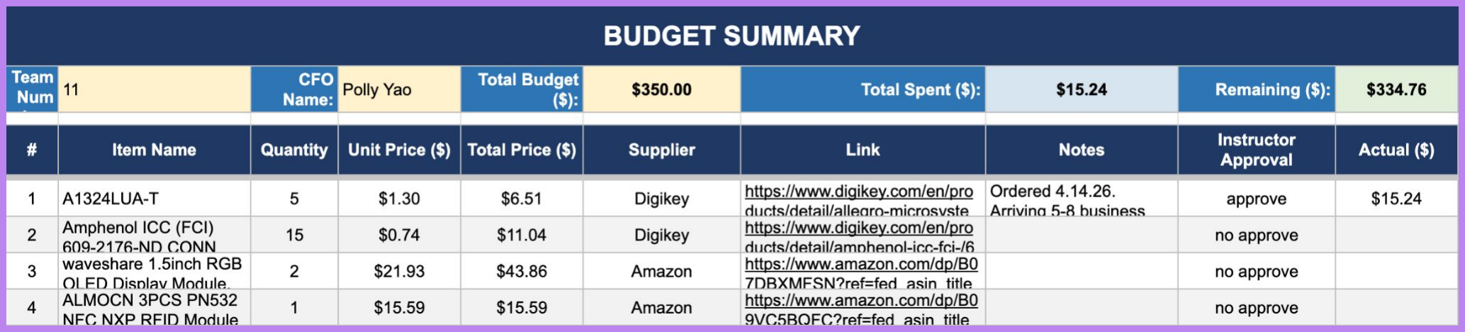
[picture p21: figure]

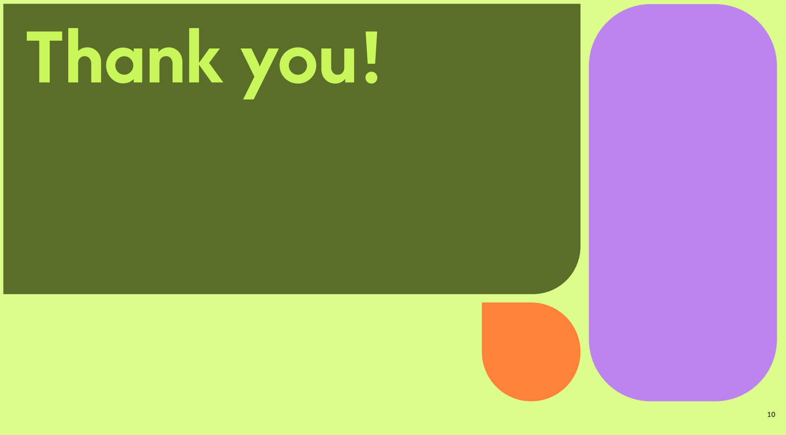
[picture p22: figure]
Thank you!

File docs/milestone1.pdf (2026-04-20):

### Modern MONOPOLY 515 Team Project Sienna&Polly

### Section1: System Mission & Boundary

- What does the system do?
The system is a hybrid board game that automatically tracks piece positions, player assets, and game events by combining a physical board with embedded sensing and digital interfaces. It coordinates gameplay in real time and reduces manual bookkeeping.
- Who is it for?
It is designed for two players who want a physical, face-to-face board game experience with reduced complexity and enhanced interaction through digital assistance.
- What hardware, software, and data does it use?
The system uses a smart board with RFID/FSR sensing, an optional camera, and a central display, along with two ESP32-based player devices with screens and NFC; software is distributed across devices to process sensing data, manage player state, and synchronize game flow using position, visual, and interaction data.

### Section2: Functional Architecture Diagram

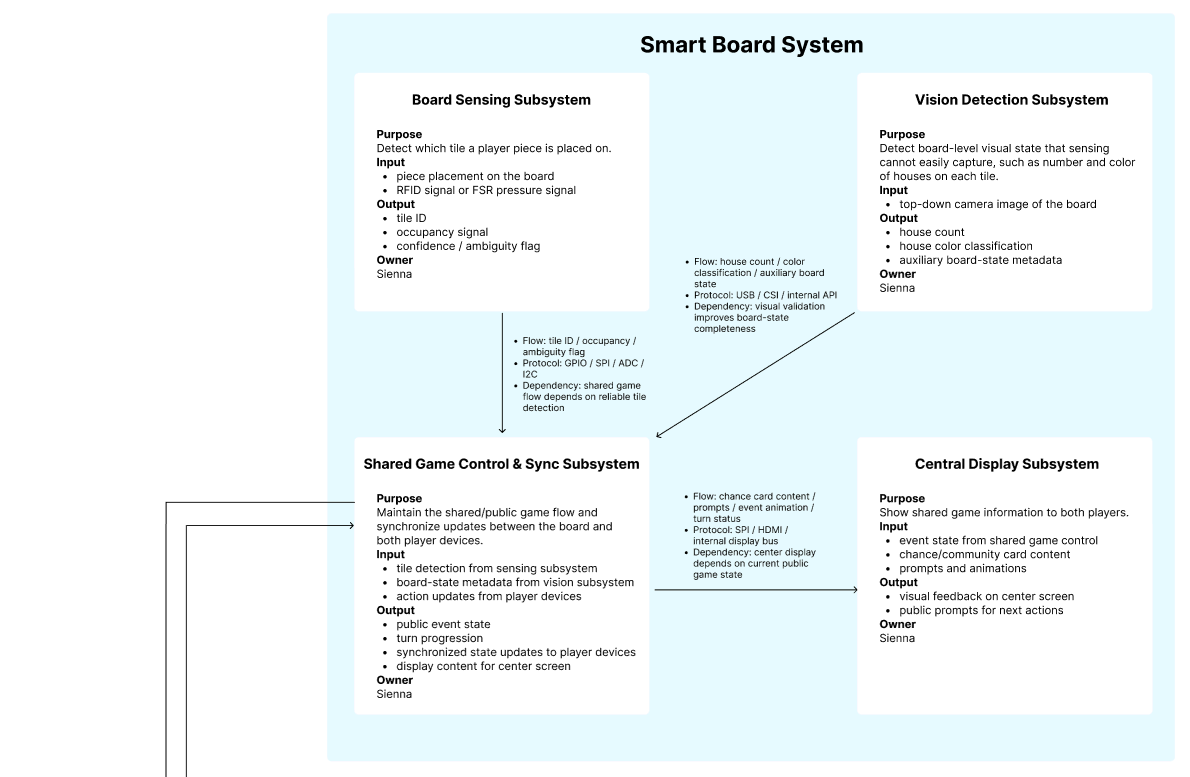
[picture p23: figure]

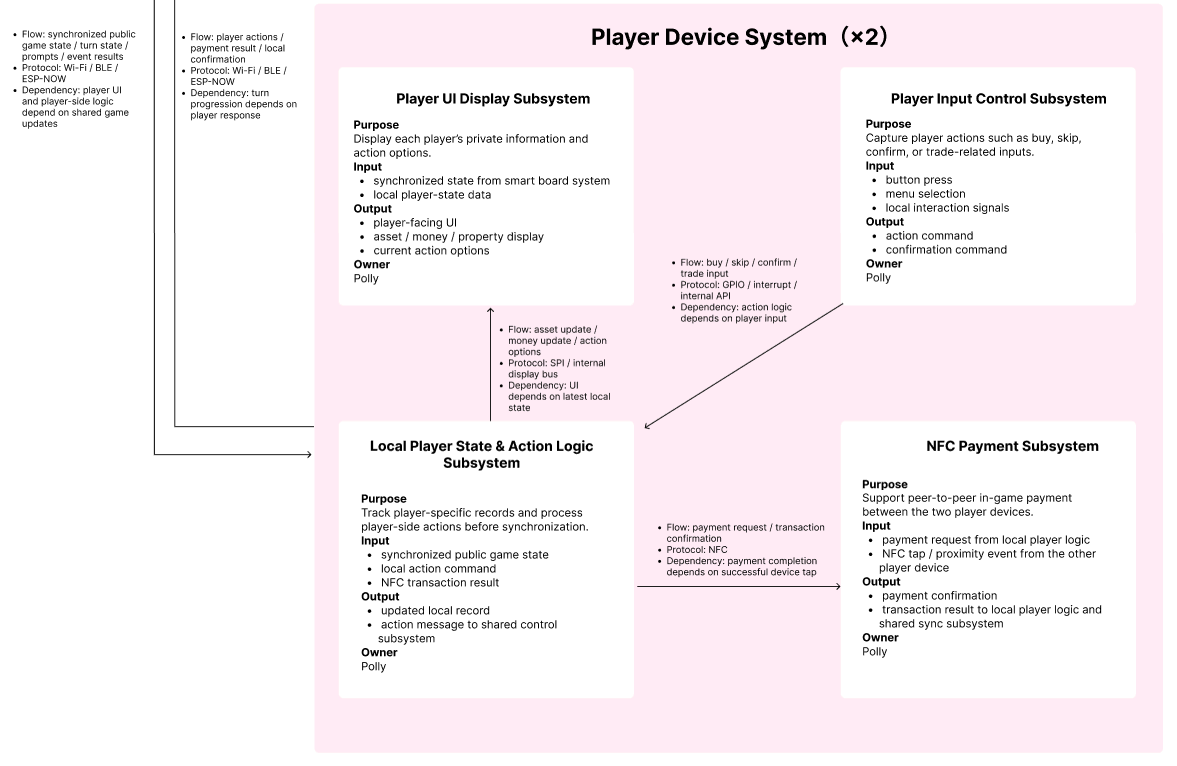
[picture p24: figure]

Feedback loop:
Player moves a piece on the board → Board Sensing Subsystem detects the tile → Shared Game Control & Sync updates the public state → Central Display shows the event or prompt → Player responds on the Player Device → Local Player State & Action Logic sends the action result back to the Shared Game Control & Sync subsystem → the system advances to the next game state.

Integrated system outcome
By combining board sensing, shared game coordination, central event display, and private player devices, the integrated system creates a synchronized hybrid board game experience that neither the board nor the player devices could produce independently.

### Section3: Risk Reduction Prototypes

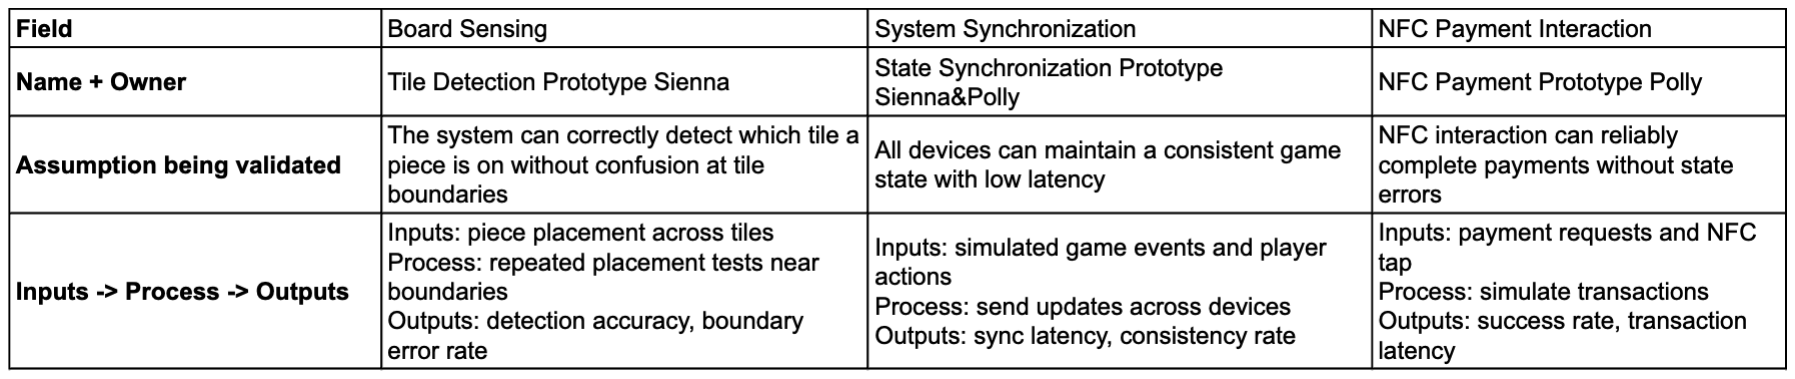
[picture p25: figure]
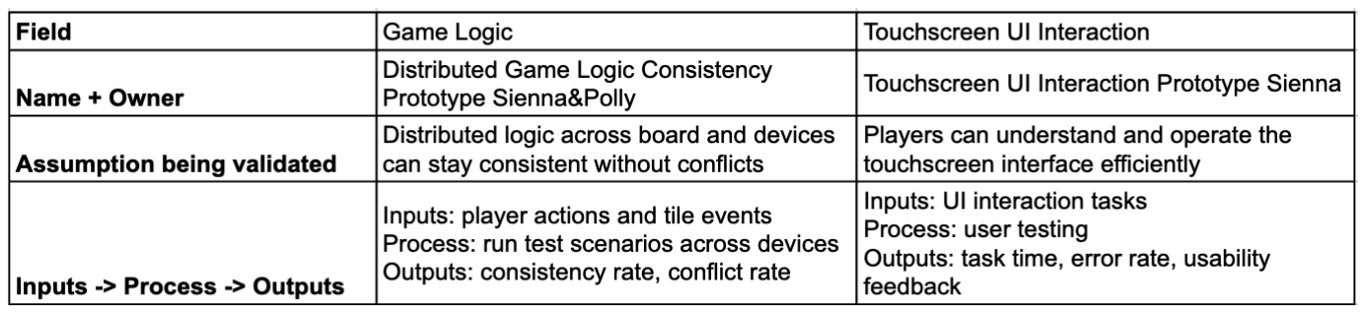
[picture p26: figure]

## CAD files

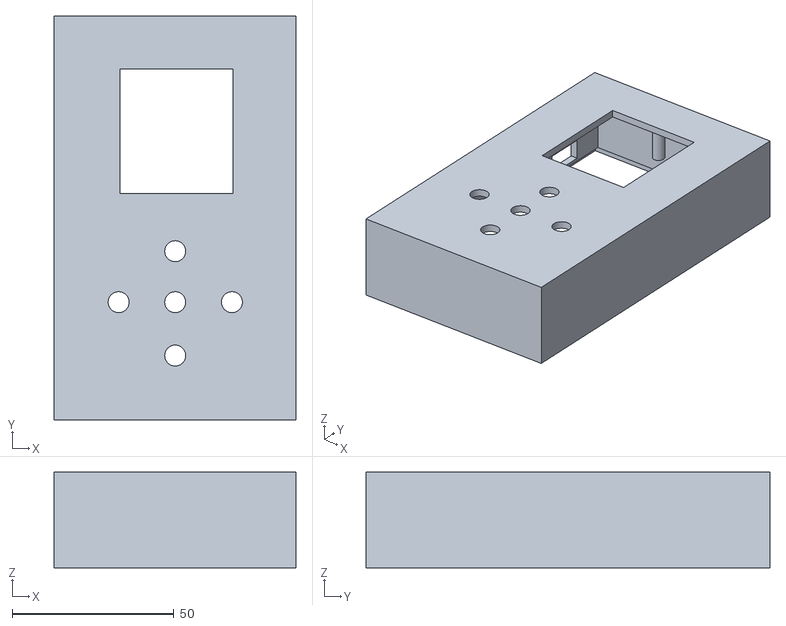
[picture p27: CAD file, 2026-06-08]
hardware/player_card_model/top.stl
74.7 x 124.8 x 29.5

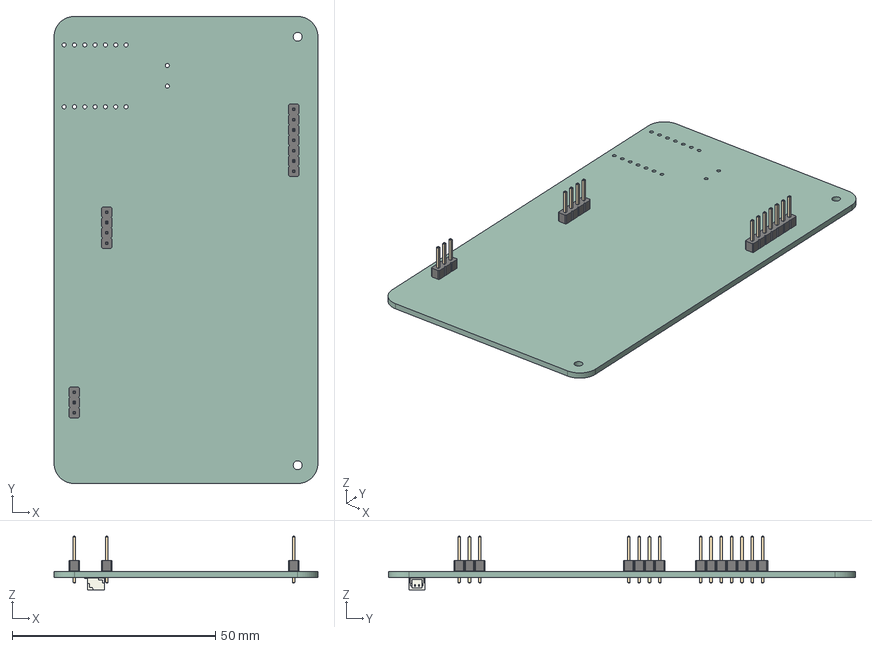
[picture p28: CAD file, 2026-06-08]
hardware/player_card_pcb/pcb model.step
65.0 x 115.0 x 13.2 mm
PinHeader_1x04_P2.54mm_Vertical
PinHeader_1x03_P2.54mm_Vertical
PinHeader_1x07_P2.54mm_Vertical
JST_SH_SM02B-SRSS-TB_1x02-1MP_P1.00mm_Horizontal
player device_PCB

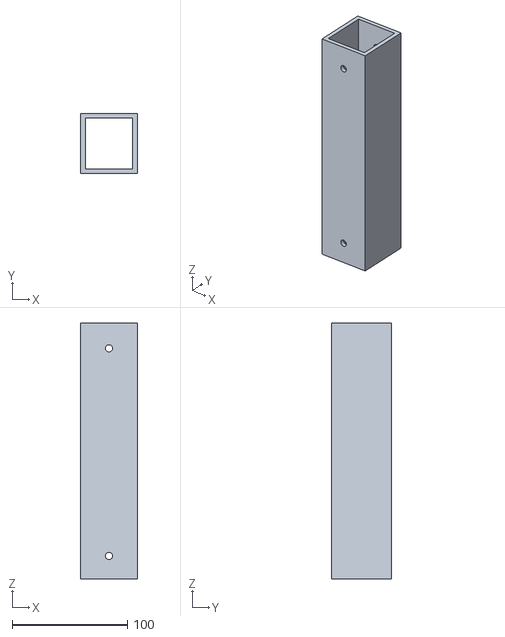
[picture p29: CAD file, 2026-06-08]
hardware/vision_archi/摄像头5.stl
49.0 x 52.0 x 222.0

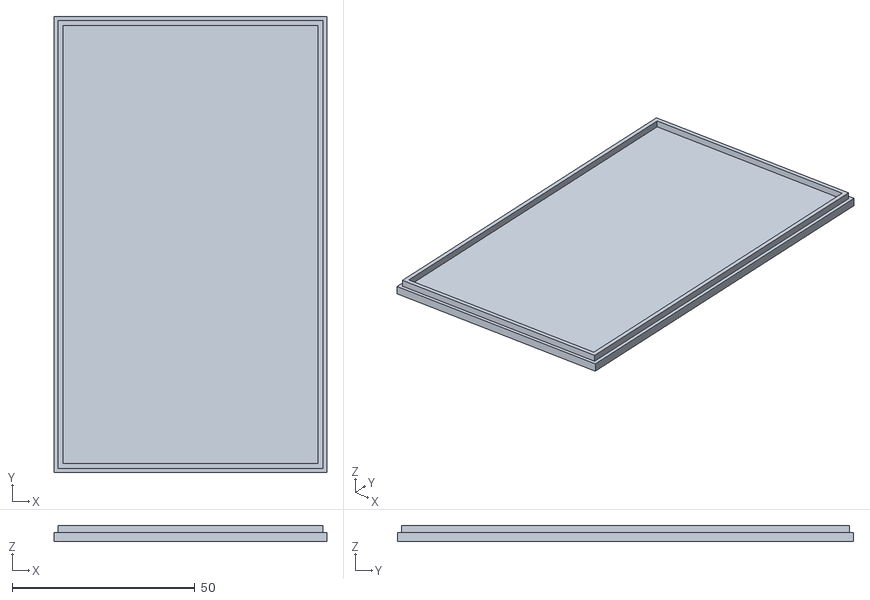
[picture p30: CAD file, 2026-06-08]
hardware/player_card_model/bottom.stl
74.7 x 124.8 x 4.50

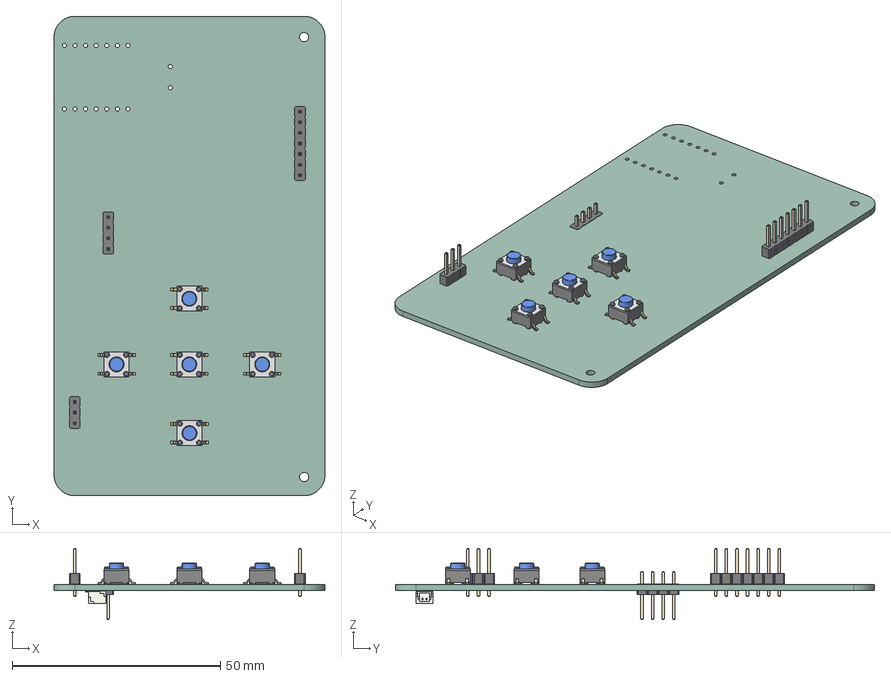
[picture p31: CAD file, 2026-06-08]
hardware/player_card_pcb/pcb model2.step
65.0 x 115.0 x 17.1 mm
TS02-66-43-BK-160_body x 5
TS02-66-43-BK-160_shield x 5
TS04-66-xx_pin x 5
TS02-66-50-BK-160_button x 5
PinHeader_1x04_P2.54mm_Vertical
PinHeader_1x03_P2.54mm_Vertical
PinHeader_1x07_P2.54mm_Vertical
JST_SH_SM02B-SRSS-TB_1x02-1MP_P1.00mm_Horizontal
player device_PCB

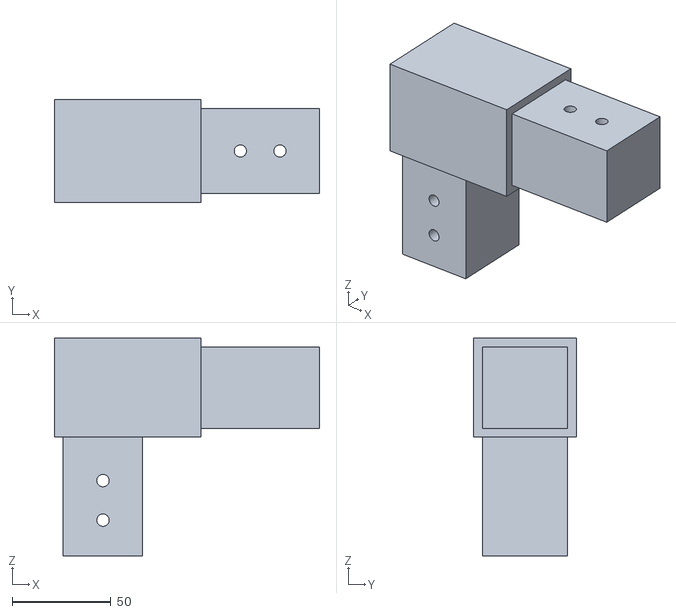
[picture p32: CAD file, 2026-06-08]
hardware/vision_archi/摄像头6.stl
134.0 x 52.0 x 110.0

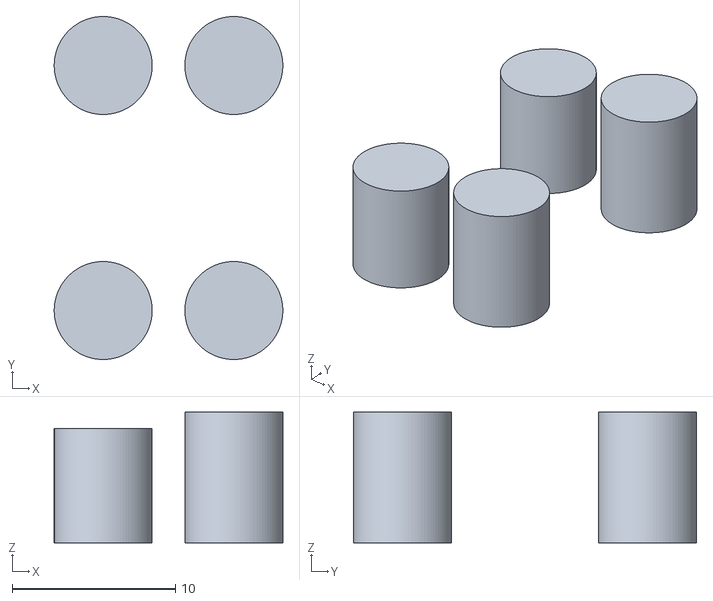
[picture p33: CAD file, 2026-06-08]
hardware/player_card_model/button_cap.stl
14.0 x 21.0 x 8.00

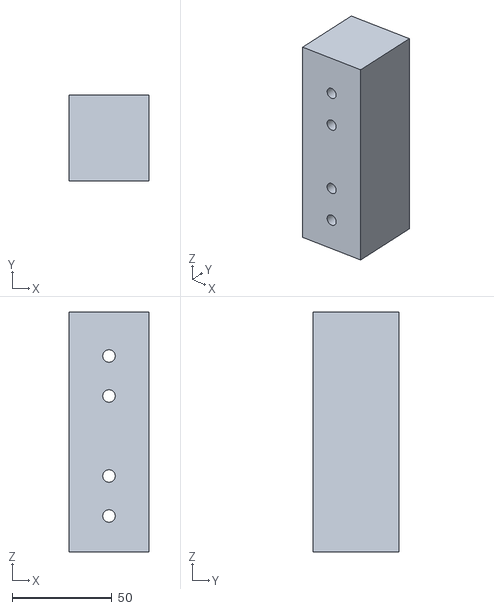
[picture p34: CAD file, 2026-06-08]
hardware/vision_archi/摄像头3.stl
40.2 x 43.2 x 120.0

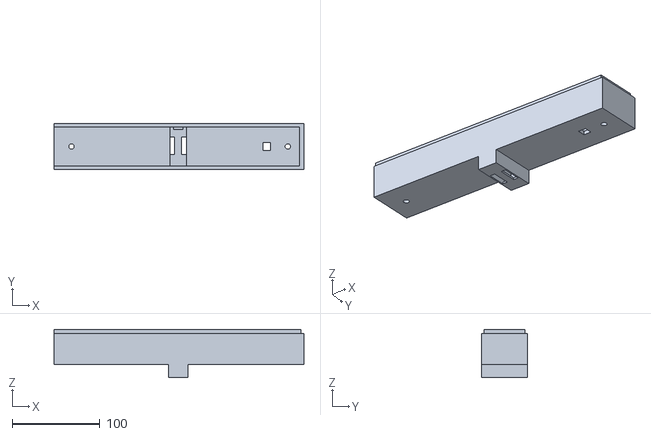
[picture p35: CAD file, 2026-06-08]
hardware/vision_archi/摄像头7.stl
285.0 x 52.0 x 54.9

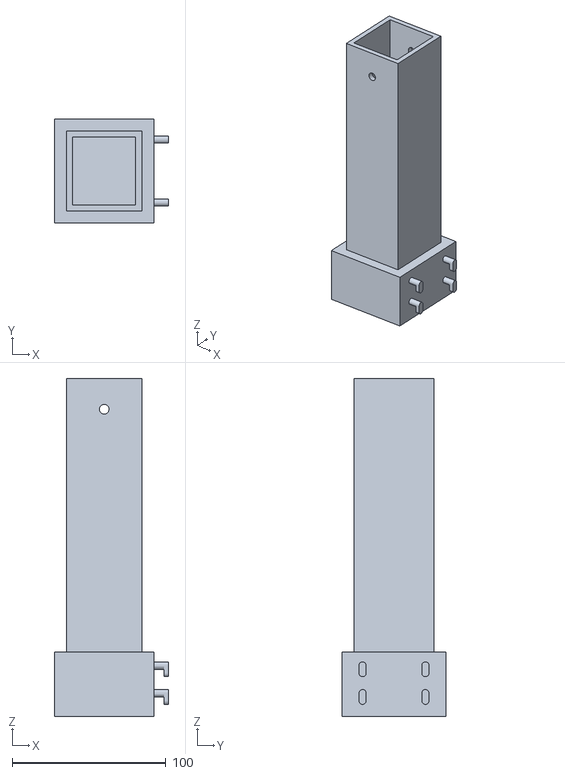
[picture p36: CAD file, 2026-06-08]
hardware/vision_archi/摄像头1.stl
74.5 x 68.0 x 220.0

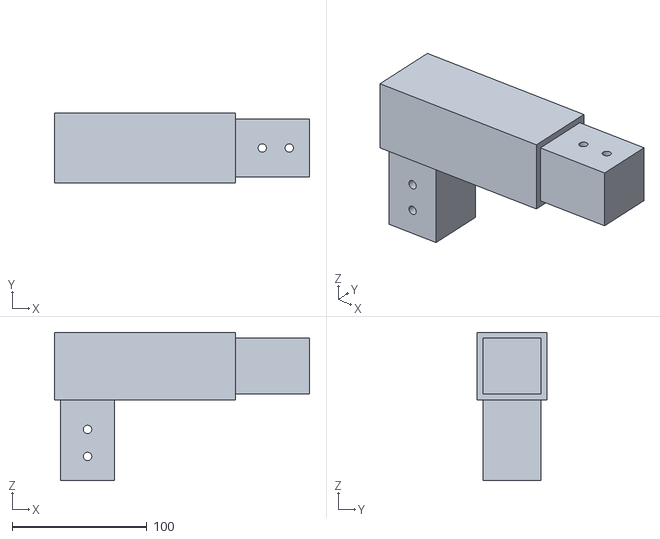
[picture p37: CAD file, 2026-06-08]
hardware/vision_archi/摄像头9.stl
189.0 x 52.0 x 110.0

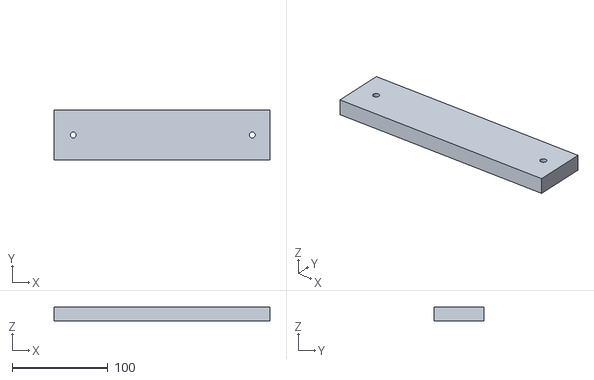
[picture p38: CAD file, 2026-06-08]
hardware/vision_archi/摄像头11.stl
225.0 x 52.0 x 15.0

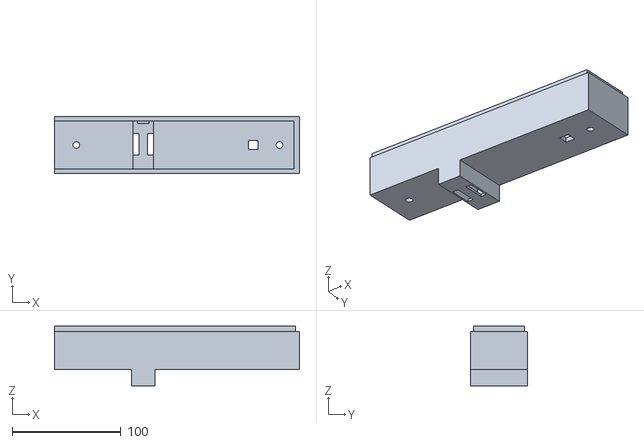
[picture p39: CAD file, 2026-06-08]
hardware/vision_archi/摄像头10.stl
225.0 x 52.0 x 54.9

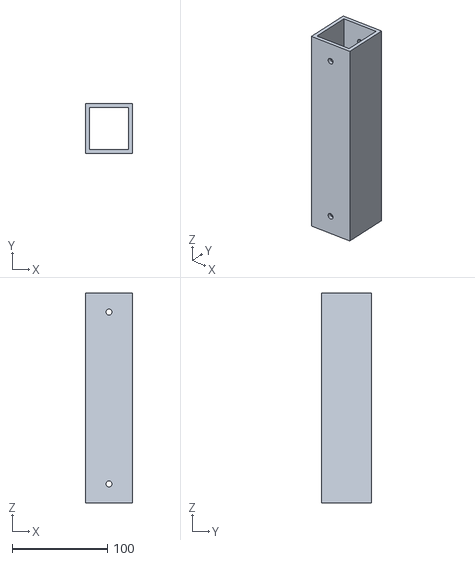
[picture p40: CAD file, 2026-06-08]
hardware/vision_archi/摄像头2.stl
49.0 x 52.0 x 220.0

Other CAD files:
hardware/player_card_pcb/.step
hardware/vision_archi/摄像头4.stl
hardware/vision_archi/摄像头8.stl
hardware/playbox+vision.f3z
hardware/player_card.f3z

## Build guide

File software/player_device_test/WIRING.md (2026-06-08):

# Monopoly Player Device — Wiring Guide

**MCU:** Seeed XIAO ESP32S3  
**Framework:** Arduino (PlatformIO)

---

## 1. OLED Display — SSD1351 (128×128, SPI)

> The SSD1351 module's RST pin is tied directly to **3.3 V** on the module itself,
> so no GPIO is consumed for reset. This frees up **D3** for the DOWN button.

| OLED Pin | Wire to | XIAO ESP32S3 Pin | Notes |
|---|---|---|---|
| VCC | → | 3.3V | Power |
| GND | → | GND | Ground |
| MOSI | → | D10 (GPIO 9) | Hardware SPI MOSI |
| SCK | → | D8  (GPIO 7) | Hardware SPI SCK |
| CS | → | D1  (GPIO 1) | Chip Select |
| DC | → | D2  (GPIO 2) | Data/Command |
| RST | → | 3.3V | **Tie to 3.3 V, NOT to a GPIO** |

**MISO (D9 / GPIO 8) is NOT connected to the OLED** — the display is write-only.
D9 is reused as the OK button.

---

## 2. NFC Reader — PN532 (I2C, 4-pin breakout)

> Before wiring, set the DIP switch on the PN532 module to **I2C mode**:  
> **SW1 = OFF, SW2 = ON** (check the silkscreen on your specific module).

| PN532 Pin | Wire to | XIAO ESP32S3 Pin | Notes |
|---|---|---|---|
| VCC | → | 3.3V | Power |
| GND | → | GND | Ground |
| SDA | → | D4  (GPIO 5) | Hardware I2C SDA |
| SCL | → | D5  (GPIO 6) | Hardware I2C SCL |

No external pull-up resistors are needed — the XIAO's internal pull-ups on the
I2C lines are sufficient for short breadboard traces.

---

## 3. Push Buttons — 5× Tactile Switch (Active LOW)

All buttons use **INPUT_PULLUP** (internal pull-up enabled in firmware).  
Connect one leg of each button to the XIAO pin; connect the other leg to **GND**.

| Button  | XIAO Pin | GPIO  | Action (short press) | Action (long press > 800 ms) |
|---|---|---|---|---|
| UP | D0 | GPIO 0 | Scroll up / prev item | — |
| DOWN | D3 | GPIO 3 | Scroll down / next item | — |
| LEFT | D6 | GPIO 43 | Back to HOME | Back to HOME |
| RIGHT | D7 | GPIO 44 | Enter next page | — |
| OK | D9 | GPIO 8  | Confirm / Select | **Advance to next player's turn** |

> **D3 (DOWN button)** is available because the OLED RST is wired to 3.3 V
> instead of a GPIO. If your SSD1351 module has RST connected to a pin by
> default, cut/lift that trace or use a module that supports hardware reset via
> VCC tie.

---

## 4. Power

| Source | Supplies |
|---|---|
| XIAO 3.3V pin | OLED VCC, PN532 VCC |
| XIAO GND | OLED GND, PN532 GND, all button GND legs |

The XIAO ESP32S3 can be powered via USB-C during development.
Total current draw (OLED backlight + PN532 + MCU) is under **200 mA**, well
within the USB 500 mA budget.

---

## 5. Pin Assignment Summary

```
XIAO ESP32S3
┌─────────────────────────────────────────┐
│  3.3V ──── OLED VCC                     │
│  3.3V ──── PN532 VCC                    │
│  3.3V ──── OLED RST  (hardware reset)   │
│  GND  ──── OLED GND / PN532 GND         │
│            / all button other legs      │
│                                         │
│  D0  (GPIO 0)  ──── BTN_UP             │
│  D1  (GPIO 1)  ──── OLED CS            │
│  D2  (GPIO 2)  ──── OLED DC            │
│  D3  (GPIO 3)  ──── BTN_DOWN           │
│  D4  (GPIO 5)  ──── PN532 SDA          │
│  D5  (GPIO 6)  ──── PN532 SCL          │
│  D6  (GPIO 43) ──── BTN_LEFT           │
│  D7  (GPIO 44) ──── BTN_RIGHT          │
│  D8  (GPIO 7)  ──── OLED SCK           │
│  D9  (GPIO 8)  ──── BTN_OK             │
│  D10 (GPIO 9)  ──── OLED MOSI          │
└─────────────────────────────────────────┘
```

---

## 6. First-time NFC Card Mapping

The firmware prints the UID of any unknown card to the serial monitor at
**115200 baud**. To map a new physical card to a board square:

1. Open the PlatformIO serial monitor: `pio device monitor -b 115200`
2. Tap the card on the PN532 reader.
3. Read the `[NFC] UID: XX XX XX XX` line.
4. Add the UID to the `nfcCards[]` array in `src/main.cpp`:

```cpp
{ { 0xXX, 0xXX, 0xXX, 0xXX }, <squareIdx> },
```

Square indices are defined in the `squares[]` array (index 0 = Go, etc.).

---

## 7. Library Dependencies (auto-installed by PlatformIO)

| Library | Version |
|---|---|
| Adafruit SSD1351 library | ≥ 1.3.2 |
| Adafruit GFX Library | ≥ 1.11.9 (auto dependency) |
| Adafruit PN532 | ≥ 1.3.2 |

Run `pio pkg install` or simply `pio run` — PlatformIO resolves and installs
all dependencies automatically from `platformio.ini`.

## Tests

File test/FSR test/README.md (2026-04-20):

# FSR Sensor Test — Seeed XIAO ESP32S3

Streams raw analog readings from a Force-Sensitive Resistor (FSR) over USB Serial at 10 Hz.

## Hardware

| Component | Connection |
|---|---|
| Seeed XIAO ESP32S3 | — |
| FSR (one leg) | Pin **D0** (GPIO 2) |
| FSR (other leg) | **GND** |
| 10 kΩ pull-down resistor | Between **D0** and **GND** |

## Prerequisites

- [PlatformIO](https://platformio.org/) (CLI or VS Code extension)
- USB-C cable

## Setup & Run

1. **Clone / open the project**

   ```bash
   cd "FSR test"
   ```

2. **Connect the board**  
   Plug the XIAO ESP32S3 into your computer via USB-C. Identify the port (e.g., `COM3` on Windows, `/dev/ttyUSB0` on Linux/macOS).

3. **Build and upload**

   ```bash
   pio run --target upload
   ```

   PlatformIO will automatically download the `espressif32` platform and the `MFRC522` library listed in `platformio.ini` on first run.

4. **Open the Serial Monitor**

   ```bash
   pio device monitor
   ```

   Baud rate is set to **115200**. You should see a stream of integer values (0–4095) printed once every 100 ms.

   ```
   312
   315
   890
   2047
   ...
   ```

   Higher values indicate more pressure on the FSR.

5. **Stop streaming** — press `Ctrl+C` in the Serial Monitor.

## Project Structure

```
FSR test/
├── src/
│   └── main.cpp        # Arduino sketch — reads FSR and streams data
├── platformio.ini      # Board and framework configuration
└── README.md
```

## How It Works

`main.cpp` calls `analogRead(D0)` every 100 ms inside `loop()` and prints the raw 12-bit ADC value (0–4095) to `Serial`. No filtering or calibration is applied; the raw value scales linearly with the voltage divider formed by the FSR and the pull-down resistor.

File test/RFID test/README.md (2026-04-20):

# Dual RFID RC522 Test — Seeed XIAO ESP32S3

Streams card UIDs from two MFRC522 RFID readers over USB Serial in real time.

## Hardware

Both readers share the board's default SPI bus (SCK / MISO / MOSI). Each reader has its own Slave-Select (SS) and Reset (RST) pin.

| Signal | RFID Reader 1 | RFID Reader 2 | XIAO ESP32S3 Pin |
|---|---|---|---|
| SDA (SS) | SDA | — | **D0** |
| RST | RST | — | **D5** |
| SDA (SS) | — | SDA | **D1** |
| RST | — | RST | **D6** |
| SCK | SCK | SCK | SCK (shared) |
| MISO | MISO | MISO | MISO (shared) |
| MOSI | MOSI | MOSI | MOSI (shared) |
| 3.3 V | VCC | VCC | 3V3 |
| GND | GND | GND | GND |

## Prerequisites

- [PlatformIO](https://platformio.org/) (CLI or VS Code extension)
- USB-C cable
- Two MFRC522 RFID modules and compatible RFID cards / tags

## Setup & Run

1. **Clone / open the project**

   ```bash
   cd "RFID test"
   ```

2. **Connect the board**  
   Plug the XIAO ESP32S3 into your computer via USB-C. Wire both RFID modules according to the table above.

3. **Build and upload**

   ```bash
   pio run --target upload
   ```

   PlatformIO will automatically download the `espressif32` platform and the `MFRC522` library (`miguelbalboa/MFRC522 @ ^1.4.10`) on first run.

4. **Open the Serial Monitor**

   ```bash
   pio device monitor
   ```

   Baud rate is **115200**. After reset you should see:

   ```
   Dual RFID RC522 Test
   RFID1 initialized
   RFID2 initialized
   Place a card near reader 1 or reader 2...
   ```

5. **Scan a card**  
   Hold an RFID card close to either reader. The UID is printed immediately:

   ```
   RFID1 detected card. UID: A3 4F 12 80
   RFID2 detected card. UID: 7B 2E 99 01
   ```

6. **Stop streaming** — press `Ctrl+C` in the Serial Monitor.

## Project Structure

```
RFID test/
├── src/
│   └── main.cpp        # Arduino sketch — polls both readers and streams UIDs
├── platformio.ini      # Board, framework, and library configuration
└── README.md
```

## How It Works

`main.cpp` initializes two `MFRC522` instances on separate SS/RST pins but the same SPI bus. Inside `loop()`, `checkReader()` is called for each reader in turn. When a new card is detected, its UID bytes are printed in hexadecimal, then the reader is halted so it is ready for the next card. The poll interval between readers is 100 ms.

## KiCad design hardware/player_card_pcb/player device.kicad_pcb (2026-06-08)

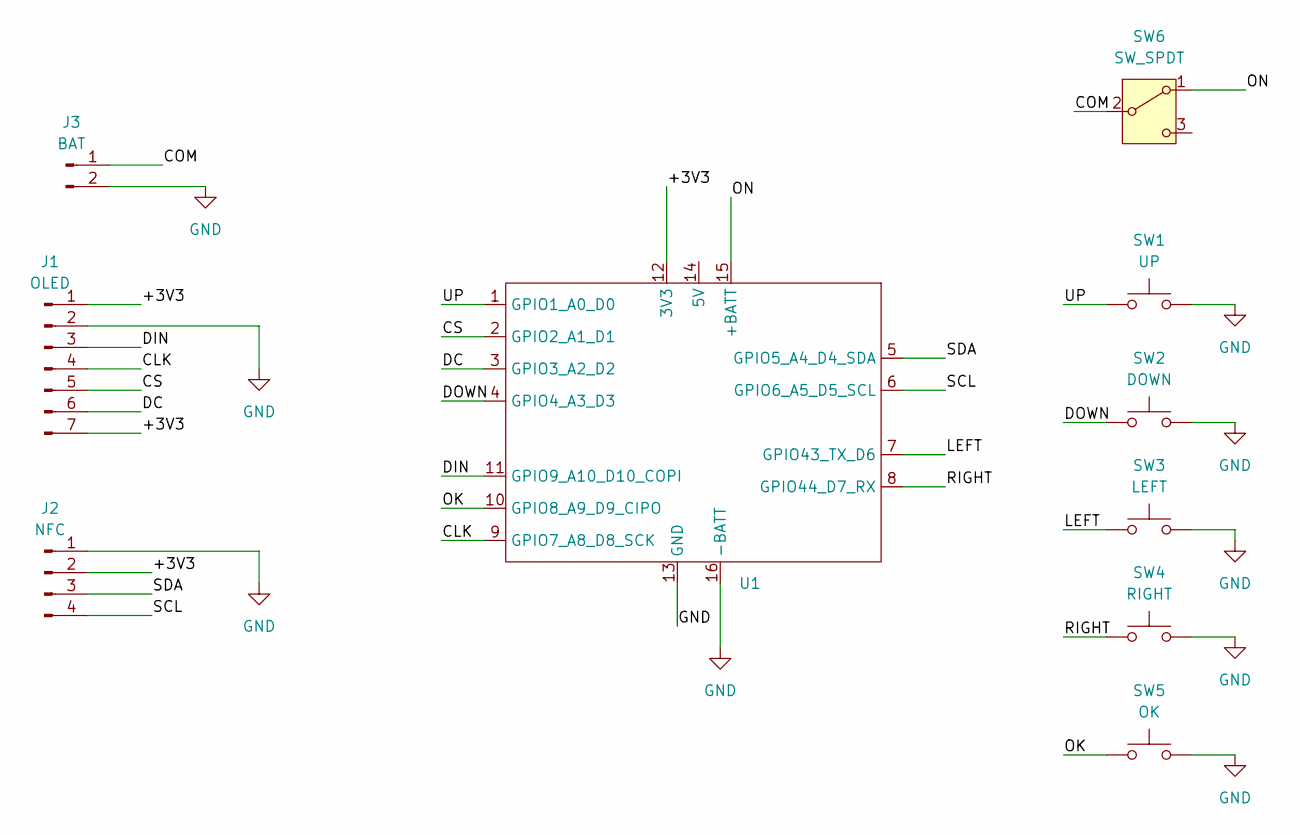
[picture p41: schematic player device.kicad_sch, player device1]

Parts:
J1: OLED; PinHeader_1x07_P2.54mm_Vertical
J2: NFC; PinHeader_1x04_P2.54mm_Vertical
J3: BAT; JST_SH_SM02B-SRSS-TB_1x02-1MP_P1.00mm_Horizontal
SW1: UP; SW_TS04-66-70-BK-260-SMT
SW2: DOWN; SW_TS04-66-70-BK-260-SMT
SW3: LEFT; SW_TS04-66-70-BK-260-SMT
SW4: RIGHT; SW_TS04-66-70-BK-260-SMT
SW5: OK; SW_TS04-66-70-BK-260-SMT
SW6: SW_SPDT; PinHeader_1x03_P2.54mm_Vertical
U1: XIAO_ESP32

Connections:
/+3V3: J1.1 (VCC), J1.7 (RST), J2.2 (VCC), U1.12 (3V3)
/CLK: J1.4 (CLK), U1.9 (GPIO7_A8_D8_SCK)
/COM: J3.1 (+), SW6.2 (B)
/CS: J1.5 (CS), U1.2 (GPIO2_A1_D1)
/DC: J1.6 (DC), U1.3 (GPIO3_A2_D2)
/DIN: J1.3 (DIN), U1.11 (GPIO9_A10_D10_COPI)
/DOWN: SW2.1, U1.4 (GPIO4_A3_D3)
/LEFT: SW3.1, U1.7 (GPIO43_TX_D6)
/OK: SW5.1, U1.10 (GPIO8_A9_D9_CIPO)
/ON: SW6.1 (A), U1.15 (+BATT)
/RIGHT: SW4.1, U1.8 (GPIO44_D7_RX)
/SCL: J2.4 (SCL), U1.6 (GPIO6_A5_D5_SCL)
/SDA: J2.3 (SDA), U1.5 (GPIO5_A4_D4_SDA)
/UP: SW1.1, U1.1 (GPIO1_A0_D0)
GND: J1.2 (GND), J2.1 (GND), J3.2 (-), SW1.2, SW2.2, SW3.2, SW4.2, SW5.2, U1.13 (GND), U1.16 (-BATT)

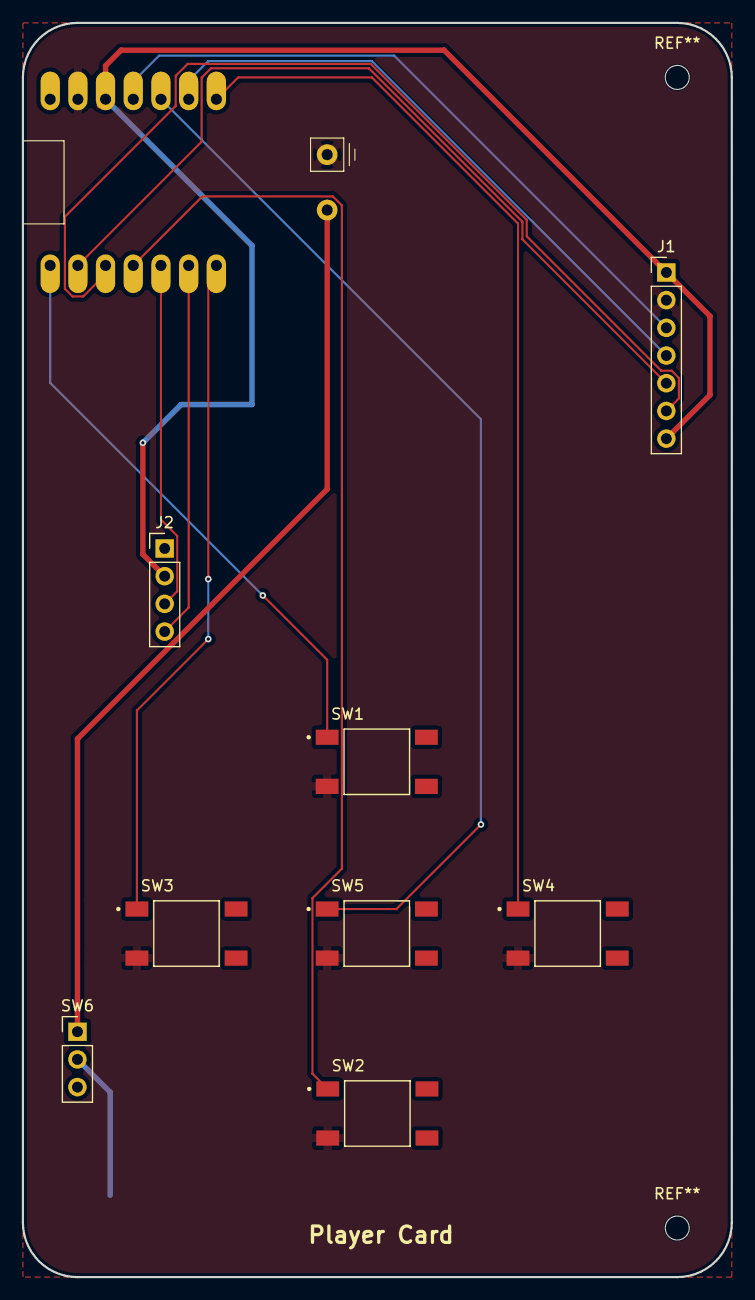
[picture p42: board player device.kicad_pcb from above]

Board: 2 copper layers, 65.0 x 115.0 mm, 10 parts (1 on the bottom side), 15 nets.

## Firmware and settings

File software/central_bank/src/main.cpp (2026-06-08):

// ============================================================
// central_bank/src/main.cpp
// CrowPanel 5" ESP32-S3 800×480 — Monopoly Central Bank
// 2-player game master: full state, dice, BLE server
//
// BLE messages OUT (notify to all players):
//   WAIT                    — waiting for players
//   START                   — both connected, game starting
//   TURN:{n}                — player n's turn (1 or 2)
//   DICE:{sum}              — dice result
//   STATE:{p1pos}:{p1bal}:{p2pos}:{p2bal}
//   ACT:GO:{amt}            — landed/passed GO
//   ACT:BUY:{name}:{price}  — purchase option (current player only)
//   ACT:RENT:{amt}:{owner}  — pay rent
//   ACT:TAX:{amt}           — tax payment
//   ACT:OWN                 — own property, no action
//   ACT:JAIL                — sent to jail (via card)
//   ACT:VISIT               — just visiting jail
//   ACT:FREE                — free parking
//   ACT:CHANCE:{text}       — chance card drawn
//   ACT:CHEST:{text}        — community chest drawn
//   ACT:BAIL:{amt}          — player paid jail bail
//   DONE                    — turn ended, state updated
//   BANKRUPT:{n}            — player n bankrupt
//   WIN:{n}                 — player n wins
//   AUCTION:{sq}:{startPrice} — auction started
//   BID:{n}:{amt}           — player n bid amt (re-broadcast)
//   AUCTION:WIN:{n}:{sq}:{price} — auction winner confirmed
//   AUCTION:NOBID           — no bids, property stays unowned
//   TRADE:{from}:{sq_offer}:{sq_want} — trade proposal broadcast
//   TRADE:DONE              — trade executed
//   TRADE:FAIL              — trade rejected
//
// BLE messages IN (write from player):
//   P{n}:HELLO              — player registration
//   P{n}:ROLL               — request dice roll
//   P{n}:BUY                — buy current property
//   P{n}:SKIP               — decline to buy → triggers auction
//   P{n}:OK                 — confirm action (pay rent/tax/etc.)
//   P{n}:BID:{amt}          — place auction bid
//   P{n}:PASS               — pass on auction (no bid)
//   P{n}:TRADE:{sq_mine}:{sq_theirs} — propose trade
//   P{n}:TRADE:YES          — accept pending trade
//   P{n}:TRADE:NO           — reject pending trade
// ============================================================

#define LGFX_USE_V1
#include <LovyanGFX.hpp>
#include <lgfx/v1/platforms/esp32s3/Panel_RGB.hpp>
#include <lgfx/v1/platforms/esp32s3/Bus_RGB.hpp>
#include <Wire.h>
#include <NimBLEDevice.h>
#include <WiFi.h>
#include <Preferences.h>
#include <esp_wifi.h>
#include <esp_event.h>
#include <esp_now.h>

// ── LovyanGFX — CrowPanel 5" V1.1 (800×480, RGB parallel) ──
class LGFX : public lgfx::LGFX_Device {
public:
  lgfx::Bus_RGB     _bus_instance;
  lgfx::Panel_RGB   _panel_instance;
  lgfx::Touch_GT911 _touch_instance;

  LGFX(void) {
    { auto cfg = _panel_instance.config();
      cfg.memory_width  = cfg.panel_width  = 800;
      cfg.memory_height = cfg.panel_height = 480;
      _panel_instance.config(cfg); }

    { auto cfg = _panel_instance.config_detail();
      cfg.use_psram = 2;   // double-buffer via PSRAM
      _panel_instance.config_detail(cfg); }

    { auto cfg = _bus_instance.config();
      cfg.panel    = &_panel_instance;
      cfg.pin_d0   = GPIO_NUM_21;  cfg.pin_d1  = GPIO_NUM_47;
      cfg.pin_d2   = GPIO_NUM_48;  cfg.pin_d3  = GPIO_NUM_45;
      cfg.pin_d4   = GPIO_NUM_38;  cfg.pin_d5  = GPIO_NUM_9;
      cfg.pin_d6   = GPIO_NUM_10;  cfg.pin_d7  = GPIO_NUM_11;
      cfg.pin_d8   = GPIO_NUM_12;  cfg.pin_d9  = GPIO_NUM_13;
      cfg.pin_d10  = GPIO_NUM_14;  cfg.pin_d11 = GPIO_NUM_7;
      cfg.pin_d12  = GPIO_NUM_17;  cfg.pin_d13 = GPIO_NUM_18;
      cfg.pin_d14  = GPIO_NUM_3;   cfg.pin_d15 = GPIO_NUM_46;
      cfg.pin_henable     = GPIO_NUM_42;
      cfg.pin_vsync       = GPIO_NUM_41;
      cfg.pin_hsync       = GPIO_NUM_40;
      cfg.pin_pclk        = GPIO_NUM_39;
      cfg.freq_write      = 16000000;  // 21MHz → 16MHz: reduce PSRAM bandwidth pressure
      cfg.hsync_polarity  = 0; cfg.hsync_front_porch = 8;
      cfg.hsync_pulse_width = 4; cfg.hsync_back_porch = 8;
      cfg.vsync_polarity  = 0; cfg.vsync_front_porch = 8;
      cfg.vsync_pulse_width = 4; cfg.vsync_back_porch = 8;
      cfg.pclk_idle_high  = 1;
      _bus_instance.config(cfg); }
    _panel_instance.setBus(&_bus_instance);

    { auto cfg = _touch_instance.config();
      cfg.x_min = 0; cfg.x_max = 800;
      cfg.y_min = 0; cfg.y_max = 480;
      cfg.pin_int = -1; cfg.pin_rst = -1;
      cfg.bus_shared = true; cfg.offset_rotation = 0;
      cfg.i2c_port = 0;
      cfg.pin_sda  = GPIO_NUM_15; cfg.pin_scl = GPIO_NUM_16;
      cfg.freq     = 400000;      cfg.i2c_addr = 0x5D;
      _touch_instance.config(cfg);
      _panel_instance.setTouch(&_touch_instance); }

    setPanel(&_panel_instance);
  }
};
static LGFX display;

// ── STC8H1K28: backlight + buzzer ───────────────────────────
#define STC_ADDR 0x30
void stcSend(uint8_t cmd) {
  Wire.beginTransmission(STC_ADDR);
  Wire.write(cmd); Wire.endTransmission();
}
void waitI2CReady() {
  while (true) {
    Wire.beginTransmission(0x30); bool a = !Wire.endTransmission();
    Wire.beginTransmission(0x5D); bool b = !Wire.endTransmission();
    if (a && b) break;
    stcSend(0x19);
    pinMode(1, OUTPUT); digitalWrite(1, LOW); delay(120);
    pinMode(1, INPUT);  delay(100);
  }
}
void beep(int ms = 80) { stcSend(0x15); delay(ms); stcSend(0x16); }
inline void flushDisp() {
  display.endWrite();
  display.waitDisplay();   // wait for vsync / DMA swap before next frame
  display.startWrite();
}

// ── Colors ───────────────────────────────────────────────────
#define C_BG      0x0B0B22UL
#define C_WHITE   0xFFFFFFUL
#define C_BLACK   0x000000UL
#define C_RED     0xFF3333UL
#define C_BLUE    0x3366FFUL
#define C_GREEN   0x22CC44UL
#define C_YELLOW  0xFFDD00UL
#define C_ORANGE  0xFF8800UL
#define C_GRAY    0x777788UL
#define C_LGRAY   0xCCCCDDUL
#define C_GOLD    0xFFD700UL
#define C_CYAN    0x00EEEDUL
#define C_PURPLE  0xAA00DDUL
#define C_PINK    0xFF66AAUL
#define C_LBLUE   0x55BBFFUL
#define C_DKBLUE  0x0A0A2AUL

// Property group accent colors
#define GRP_NONE   0x2A2A4AUL
#define GRP_PURPLE 0x60B840UL  // visible green
#define GRP_LBLUE  0xE0C880UL  // warm tan (visible, not white, not pure yellow)
#define GRP_PINK   0x4A4A4AUL  // dark grey
#define GRP_ORANGE 0xA0522DUL  // sienna
#define GRP_RED    0xFF8800UL  // orange
#define GRP_YELLOW 0xFFD43BUL
#define GRP_GREEN  0xC09070UL  // light brown
#define GRP_DBLUE  0x2255CCUL

static const uint32_t P_COLOR[2] = { C_RED, C_BLUE };

// ── Board: 20 squares ────────────────────────────────────────
#define NUM_SQ     40
#define NUM_PLY     2
#define START_BAL 1500
#define GO_BONUS   200
#define JAIL_SQ     10

enum SqType {
  SQ_GO, SQ_PROPERTY, SQ_RAILROAD, SQ_UTILITY,
  SQ_TAX, SQ_CHANCE, SQ_CHEST, SQ_JAIL,
  SQ_GOTO_JAIL, SQ_FREE_PARK
};

struct Square {
  const char* name;    // display name (max ~12 chars for cell)
  SqType      type;
  int         price;   // 0 = not buyable
  int         value;   // rent, tax amount, or utility fixed rent
  uint32_t    grp;     // group color for property bar
};

// 20 squares arranged in a 4-column × 5-row grid on screen
static const Square SQ[NUM_SQ] = {
  // idx  name            type          price  value    grp
  { "GO",            SQ_GO,          0,    0,    GRP_NONE   },  //  0
  { "Old Kent Road", SQ_PROPERTY,   60,    2,    GRP_PURPLE },  //  1
  { "Community Chest", SQ_CHEST,    0,    0,    GRP_NONE   },  //  2
  { "Whitechapel Road", SQ_PROPERTY, 60,   4,    GRP_PURPLE },  //  3
  { "Income Tax",    SQ_TAX,         0,  200,    GRP_NONE   },  //  4
  { "King's Cross Station", SQ_RAILROAD, 200, 25, GRP_NONE   },  //  5
  { "The Angel Islington", SQ_PROPERTY, 100,  6,  GRP_LBLUE  },  //  6
  { "Chance",        SQ_CHANCE,      0,    0,    GRP_NONE   },  //  7
  { "Euston Road",   SQ_PROPERTY,  100,    6,    GRP_LBLUE  },  //  8
  { "Pentonville Road", SQ_PROPERTY, 120,  8,    GRP_LBLUE  },  //  9
  { "Jail / Just Visiting", SQ_JAIL, 0,    0,    GRP_NONE   },  // 10
  { "Pall Mall",     SQ_PROPERTY,  140,   10,    GRP_PINK   },  // 11
  { "Electric Company", SQ_UTILITY, 150,  75,    GRP_NONE   },  // 12
  { "Whitehall",     SQ_PROPERTY,  140,   10,    GRP_PINK   },  // 13
  { "Northumberland Avenue", SQ_PROPERTY, 160, 12, GRP_PINK },  // 14
  { "Marylebone Station", SQ_RAILROAD, 200, 25, GRP_NONE   },  // 15
  { "Bow Street",    SQ_PROPERTY,  180,   14,    GRP_ORANGE },  // 16
  { "Community Chest", SQ_CHEST,    0,    0,    GRP_NONE   },  // 17
  { "Marlborough Street", SQ_PROPERTY, 180, 14, GRP_ORANGE },  // 18
  { "Vine Street",   SQ_PROPERTY,  200,   16,    GRP_ORANGE },  // 19
  { "Free Parking",  SQ_FREE_PARK,   0,    0,    GRP_NONE   },  // 20
  { "Strand",        SQ_PROPERTY,  220,   18,    GRP_RED    },  // 21
  { "Chance",        SQ_CHANCE,      0,    0,    GRP_NONE   },  // 22
  { "Fleet Street",  SQ_PROPERTY,  220,   18,    GRP_RED    },  // 23
  { "Trafalgar Square", SQ_PROPERTY, 240, 20,    GRP_RED    },  // 24
  { "Fenchurch St. Station", SQ_RAILROAD, 200, 25, GRP_NONE },  // 25
  { "Leicester Square", SQ_PROPERTY, 260, 22,    GRP_YELLOW },  // 26
  { "Coventry Street", SQ_PROPERTY, 260,  22,    GRP_YELLOW },  // 27
  { "Water Works",   SQ_UTILITY,   150,   75,    GRP_NONE   },  // 28
  { "Piccadilly",    SQ_PROPERTY,  280,   24,    GRP_YELLOW },  // 29
  { "Go To Jail",    SQ_GOTO_JAIL,   0,    0,    GRP_NONE   },  // 30
  { "Regent Street", SQ_PROPERTY,  300,   26,    GRP_GREEN  },  // 31
  { "Oxford Street", SQ_PROPERTY,  300,   26,    GRP_GREEN  },  // 32
  { "Community Chest", SQ_CHEST,    0,    0,    GRP_NONE   },  // 33
  { "Bond Street",   SQ_PROPERTY,  320,   28,    GRP_GREEN  },  // 34
  { "Liverpool St. Station", SQ_RAILROAD, 200, 25, GRP_NONE },  // 35
  { "Chance",        SQ_CHANCE,      0,    0,    GRP_NONE   },  // 36
  { "Park Lane",     SQ_PROPERTY,  350,   35,    GRP_DBLUE  },  // 37
  { "Super Tax",     SQ_TAX,         0,  100,    GRP_NONE   },  // 38
  { "Mayfair",       SQ_PROPERTY,  400,   50,    GRP_DBLUE  },  // 39
};

// ── Chance / Community Chest cards ───────────────────────────
struct Card { const char* text; int delta; bool toJail; bool toGO; };

static const Card CHANCE[] = {
  { "Advance to GO! +$200",     200, false, true  },
  { "Bank dividend +$50",        50, false, false },
  { "Go to Jail",                 0, true,  false },
  { "Pay poor tax -$15",        -15, false, false },
  { "General repairs -$40",     -40, false, false },
};
static const Card CHEST[] = {
  { "Bank error! +$200",        200, false, false },
  { "Doctor fees -$50",         -50, false, false },
  { "Life insurance +$100",     100, false, false },
  { "School fees -$150",       -150, false, false },
  { "Services rendered +$25",    25, false, false },
};
#define CHANCE_N 5
#define CHEST_N  5
#define AUCTION_DURATION_MS 60000UL
#define BANK_LOAN_LIMIT 500

// ── Game State ───────────────────────────────────────────────
struct Player {
  char name[16];
  int  balance;
  int  position;
  bool inJail;
  bool connected;
  bool owns[NUM_SQ];   // which squares this player owns
};

enum Phase {
  PH_WAIT_PLAYERS,   // waiting for both to connect
  PH_LOBBY,          // both connected, 3s countdown
  PH_TURN_START,     // announce whose turn, send TURN msg
  PH_WAIT_ROLL,      // waiting for player to roll (touch or BLE)
  PH_DICE_ANIM,      // running dice animation (blocking)
  PH_WAIT_ACTION,    // square needs player decision (BUY/SKIP/OK) — wait for BLE from player card
  PH_ACTION_RESULT,  // show event result 3.5s then advance turn
  PH_AUCTION,        // auction running — 10s bid timer, auctioneer display
  PH_WAIT_TRADE,     // waiting for trade response from other player (30s timeout)
  PH_GAME_OVER,
  PH_CONFLICT,       // camera detected house/hotel mismatch — confirm or calibrate
  PH_CALIBRATE,      // camera coordinate calibration UI
  PH_CONFIRM_RESTART // mid-game restart confirmation screen
};

struct GameState {
  Player  P[NUM_PLY];
  int     sqOwner[NUM_SQ];   // -1, 0, or 1
  int     cur;               // current player index (0 or 1)
  Phase   phase;
  uint32_t phaseMs;          // millis() when phase was entered
  int     winner;            // -1, 0, or 1
  int     dice1, dice2;
  bool    lastRollWasDouble;  // current player gets another turn after resolving action
  int     doublesCount[NUM_PLY];
  char    evtMsg[96];        // event description for info panel
  bool    needRedraw;
  // Auction state
  int     auctionSq;         // square being auctioned (-1 = none)
  int     auctionBid;        // current highest bid (0 = no bids)
  int     auctionBidder;     // player index of highest bidder (-1 = none)
  uint32_t auctionTimerMs;   // millis() when auction timer last reset
  // Trade state
  int     tradeFrom;         // player index proposing trade
  int     tradeSqOffer;      // square being offered
  int     tradeSqWant;       // square being requested
  // Resend state: last ACT message that requires P1 response
  char    pendingActMsg[80]; // stored ACT:* message for resend
  uint32_t lastResendMs;     // millis() of last resend (or initial send)
  // House/hotel system records (camera integration)
  int     sysHouses[NUM_SQ];
  int     sysHotels[NUM_SQ];
  // Conflict / calibration state
  Phase   savedPhase;        // phase to return to after conflict/calibration
} G;

struct SaveData {
  uint32_t magic;
  uint16_t version;
  int      phase;
  int      savedPhase;
  Player   P[NUM_PLY];
  int      sqOwner[NUM_SQ];
  int      cur;
  int      winner;
  int      dice1, dice2;
  bool     lastRollWasDouble;
  int      doublesCount[NUM_PLY];
  char     evtMsg[96];
  int      auctionSq;
  int      auctionBid;
  int      auctionBidder;
  uint32_t auctionRemainingMs;
  int      tradeFrom;
  int      tradeSqOffer;
  int      tradeSqWant;
  char     pendingActMsg[80];
  int      sysHouses[NUM_SQ];
  int      sysHotels[NUM_SQ];
  bool     ignoredConflict[NUM_SQ];
  int      ignoredCamHouses[NUM_SQ], ignoredCamHotels[NUM_SQ];
  int      ignoredSysHouses[NUM_SQ], ignoredSysHotels[NUM_SQ];
};

static Preferences savePrefs;
static bool saveReady = false;
static const uint32_t SAVE_MAGIC = 0x4D4F4E4FUL;  // MONO
static const uint16_t SAVE_VERSION = 2;

// ── Camera ESP-NOW ──────────────────────────────────────────
// Camera (sender) MAC address — 替换为你的 camera 实际 MAC
static uint8_t cameraMAC[] = {0x58, 0x8C, 0x81, 0x9E, 0x62, 0xCC};
static volatile bool  cameraConnected = false;
static volatile bool  camDataReady    = false;
static char           camRxBuf[512]   = "";
static bool           espNowInited    = false;
static const uint8_t  ESPNOW_CHANNEL  = 1;

// Camera-detected board state (indexed by game square 0-39)
struct CameraCell { uint8_t houses; uint8_t hotels; };
static CameraCell camBoard[NUM_SQ];
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
void loop() {
  // Process incoming BLE message (flag set by BLE task)
  if (bleRxNew) {
    bleRxNew = false;
    char msg[72]; strncpy(msg, bleRxBuf, 71); msg[71] = '\0';
    handleBLERx(msg);
  }

  updateBlePause();
  if (blePauseActive) {
    if (G.needRedraw) {
      drawBlePausedOverlay();
      G.needRedraw = false;
    }
    delay(16);
    return;
  }

  // ── Camera data processing ──────────────────────────────────
  static uint32_t lastCamDataMs = millis();
  if (camDataReady) {
    camDataReady = false;
    lastCamDataMs = millis();
    char jsonCopy[512];
    strncpy(jsonCopy, camRxBuf, sizeof(jsonCopy) - 1);
    jsonCopy[sizeof(jsonCopy) - 1] = '\0';
    parseCamJson(jsonCopy);
    detectConflicts();
    if (conflictCount > 0 &&
        G.phase != PH_CONFLICT && G.phase != PH_CALIBRATE) {
      G.savedPhase = G.phase;
      enterPhase(PH_CONFLICT);
    }
  }

  // Camera timeout: if no ESP-NOW data for 15s, mark disconnected
  if (cameraConnected && millis() - lastCamDataMs > 15000) {
    cameraConnected = false;
    G.needRedraw = true;
    Serial0.println("[CAM] No data for 15s, marked disconnected");
  }

  // Touch input
  static bool wasTouched = false;
  lgfx::touch_point_t tp[1];
  bool touched = display.getTouch(tp, 1) > 0;
  bool freshTouch = touched && !wasTouched;
  wasTouched = touched;

  // Mid-game restart: RST button in top-right corner during gameplay
  if (freshTouch && isGameplayPhase(G.phase) &&
      G.phase != PH_CONFIRM_RESTART && G.phase != PH_CONFLICT && G.phase != PH_CALIBRATE) {
    if (hitRect(tp[0].x, tp[0].y, rstBtn)) {
      beep(40);
      G.savedPhase = G.phase;  // save in case user cancels
      enterPhase(PH_CONFIRM_RESTART);
    }
  }

  switch (G.phase) {

    case PH_WAIT_PLAYERS:
      if (G.needRedraw) { drawWaitScreen(); G.needRedraw = false; }
      // In single-device mode: start once P1 (the real device) connects.
      // Auto-mark P2 as connected so the rest of the game logic is unaffected.
#if SINGLE_DEVICE_TEST
      if (G.P[0].connected && !G.P[1].connected) {
        G.P[1].connected = true;
        G.needRedraw = true;
      }
#endif
      // Transition when both players AND camera are connected
      if (G.P[0].connected && G.P[1].connected && cameraConnected) {
        sendAll("START");
        snprintf(G.evtMsg, sizeof(G.evtMsg), "All devices connected!");
        enterPhase(PH_LOBBY);
      }
      break;

    case PH_LOBBY:
      if (G.needRedraw) { drawWaitScreen(); G.needRedraw = false; }
      if (freshTouch) {
        initGame();
        G.P[0].connected = true;
        G.P[1].connected = true;
        enterPhase(PH_TURN_START);
      }
      break;

    case PH_TURN_START: {
      if (G.needRedraw) {
        // Handle jail: auto-pay $50 bail at turn start
        if (G.P[G.cur].inJail) {
          G.P[G.cur].balance -= 50;
          G.P[G.cur].inJail   = false;
          G.doublesCount[G.cur] = 0;
          G.lastRollWasDouble = false;
          snprintf(G.evtMsg, sizeof(G.evtMsg),
            "P%d paid $50 jail bail", G.cur+1);
          sendAll("ACT:BAIL:50");
          sendState();
        }
        char buf[16];
        snprintf(buf, sizeof(buf), "TURN:%d", G.cur+1);
        sendAll(buf);
        drawTurnScreen(G.cur, false);
        G.needRedraw = false;
      }
      if (freshTouch) enterPhase(PH_WAIT_ROLL);
#if SINGLE_DEVICE_TEST
      // P2 has no human — auto-advance its turn start after 1s
      if (G.cur == 1 && phaseElapsed(1000)) enterPhase(PH_WAIT_ROLL);
#endif
      break;
    }

    case PH_WAIT_ROLL:
      if (G.needRedraw) { drawTurnScreen(G.cur, true); G.needRedraw = false; }
      // Touch the centered ROLL DICE button (x:200-600, y:358-440)
      if (freshTouch &&
          tp[0].x >= 200 && tp[0].x <= 600 &&
          tp[0].y >= 358 && tp[0].y <= 440) {
        enterPhase(PH_DICE_ANIM);
      }
#if SINGLE_DEVICE_TEST
      // Auto-roll for P2 (index 1) after 2s
      if (G.cur == 1 && phaseElapsed(2000)) {
        enterPhase(PH_DICE_ANIM);
      }
#endif
      // Heartbeat: re-broadcast TURN+STATE every 5s for P1 (real device).
      // Fixes the case where the initial TURN notify was dropped and the player
      // card is stuck — no HELLO needed, central keeps trying automatically.
      if (G.cur == 0 && millis() - G.lastResendMs >= 3000) {
        G.lastResendMs = millis();
        char hb[16]; snprintf(hb, sizeof(hb), "TURN:%d", G.cur + 1);
        sendAll(hb);
        delay(40);
        sendState();
        Serial0.println("[HEARTBEAT] Re-sent TURN+STATE in PH_WAIT_ROLL");
      }
      break;

    case PH_DICE_ANIM:
      runDiceAnim();  // blocking — sets phase via processSquare → endTurn
      G.needRedraw = true;
      break;

    case PH_WAIT_ACTION: {
      if (G.needRedraw) { drawSquareLanding(G.cur, G.P[G.cur].position); G.needRedraw = false; }
      // Resend the pending ACT message every 4s for P1 (real device) in case
      // the BLE notification was dropped and the player card never received it.
      if (G.cur == 0 && G.pendingActMsg[0] &&
          millis() - G.lastResendMs >= 3000) {
        G.lastResendMs = millis();
        sendState();
        delay(40);
        sendAll(G.pendingActMsg);
        Serial0.printf("[RESEND] %s\n", G.pendingActMsg);
      }
      // Central bank display only — no touch action buttons.
      // Player card sends BLE messages (BUY/SKIP/OK) handled in handleBLERx().
      // For info-only squares (GO/JAIL/OWN/FREE): also advance on central touch.
      if (freshTouch) {
        int sq = G.P[G.cur].position;
        SqType t = SQ[sq].type;
        bool isInfo = (t == SQ_GO || t == SQ_JAIL || t == SQ_GOTO_JAIL || t == SQ_FREE_PARK);
        if (t == SQ_PROPERTY || t == SQ_RAILROAD || t == SQ_UTILITY)
          isInfo = isInfo || (G.sqOwner[sq] == G.cur);
        if (isInfo) {
          snprintf(G.evtMsg, sizeof(G.evtMsg), "P%d: %s", G.cur+1, SQ[sq].name);
          endTurn();
        }
      }
#if SINGLE_DEVICE_TEST
      // Auto-decide for P2 (index 1) after 2.5s
      if (G.cur == 1 && phaseElapsed(2500)) {
        int sq2 = G.P[1].position;
        SqType t2 = SQ[sq2].type;
        bool buyable2 = (t2 == SQ_PROPERTY || t2 == SQ_RAILROAD || t2 == SQ_UTILITY);
        if (buyable2 && G.sqOwner[sq2] == -1) {
          if (G.P[1].balance >= SQ[sq2].price) {
            G.P[1].balance -= SQ[sq2].price;
            G.sqOwner[sq2]   = 1;
            G.P[1].owns[sq2] = true;
            snprintf(G.evtMsg, sizeof(G.evtMsg),
              "P2 (auto) bought %s $%d", SQ[sq2].name, SQ[sq2].price);
          } else {
            // Auto-skip → trigger auction
            G.auctionSq      = sq2;
            G.auctionBid     = 0;
            G.auctionBidder  = -1;
            G.auctionTimerMs = millis();
            char buf[32];
            snprintf(buf, sizeof(buf), "AUCTION:%d:%d", sq2, SQ[sq2].price);
            sendAll(buf);
            enterPhase(PH_AUCTION);
            break;
          }
        } else {
          snprintf(G.evtMsg, sizeof(G.evtMsg), "P2 (auto) %s", SQ[sq2].name);
        }
        if (G.phase == PH_WAIT_ACTION) endTurn();
      }
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

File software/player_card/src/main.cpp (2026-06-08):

// ============================================================
// player_card/src/main.cpp
// Seeed XIAO ESP32S3 — Monopoly Player Card (2-player game)
// Hardware: SSD1351 128×128 OLED + PN532 NFC + 5 buttons
//
// Change PLAYER_NUM in platformio.ini build_flags:
//   -DPLAYER_NUM=1   (first player device)
//   -DPLAYER_NUM=2   (second player device)
//
// Buttons:
//   OK    (D9) — confirm / roll dice / buy
//   LEFT  (D6) — back / skip / cancel
//   RIGHT (D7) — alternate action
//   UP    (D0) — scroll up / view properties
//   DOWN  (D4) — scroll down / view cards
//
// BLE messages IN (from central, notify):
//   WAIT | START | TURN:{n} | DICE:{sum}
//   STATE:{p1pos}:{p1bal}:{p2pos}:{p2bal}
//   ACT:GO:{amt} | ACT:BUY:{name}:{price}
//   ACT:RENT:{amt}:{who} | ACT:TAX:{amt}
//   ACT:OWN | ACT:JAIL | ACT:VISIT | ACT:FREE
//   ACT:CHANCE:{text} | ACT:CHEST:{text} | ACT:BAIL:{amt}
//   AUCTION:{sq}:{startPrice} | BID:{playerNum}:{amt}
//   AUCTION:WIN:{n}:{sq}:{price} | AUCTION:NOBID
//   DONE | BANKRUPT:{n} | WIN:{n}
//
// BLE messages OUT (write to central):
//   P{n}:HELLO | P{n}:ROLL | P{n}:BUY | P{n}:SKIP | P{n}:OK
//   P{n}:BID:{amt} | P{n}:PASS
// ============================================================

#include <Arduino.h>
#include "soc/soc.h"
#include "soc/rtc_cntl_reg.h"
#include <SPI.h>
#include <Wire.h>
#include <Adafruit_GFX.h>
#include <Adafruit_SSD1351.h>
#include <Adafruit_PN532.h>
#include <NimBLEDevice.h>

// ── Player identity ──────────────────────────────────────────
#ifndef PLAYER_NUM
#define PLAYER_NUM 1
#endif
#define MY_IDX (PLAYER_NUM - 1)   // 0-based index

// ── OLED SPI pins (XIAO ESP32S3) ────────────────────────────
#define OLED_CS   D1
#define OLED_DC   D2
#define OLED_RST  D3
// SPI: SCK=D8(GPIO7), MOSI=D10(GPIO9)

// ── Button pins (active LOW, INPUT_PULLUP) ───────────────────
#define BTN_OK    D9
#define BTN_LEFT  D6
#define BTN_RIGHT D7
#define BTN_UP    D0

// ── OLED colors (RGB565) ─────────────────────────────────────
#define C_BLACK   0x0000
#define C_WHITE   0xFFFF
#define C_RED     0xF800
#define C_BLUE    0x339F  // 0x3366FF → RGB565
#define C_GREEN   0x07E0
#define C_YELLOW  0xFFE0
#define C_ORANGE  0xFD20
#define C_CYAN    0x07FF
#define C_MAGENTA 0xF81F
#define C_GRAY    0x7BEF
#define C_LGRAY   0xC618
#define C_DKGRAY  0x39E7
#define C_GOLD    0xFEA0
#define C_PURPLE  0x781F
#define C_PINK    0xFC18
#define C_BROWN   0x8200
#define C_LBLUE   0x5D9F
#define C_PROP_LGREEN 0x65C8  // visible green (~0x60,0xB8,0x40)
#define C_PROP_LYELLOW 0xE650  // warm tan (visible, not white, not pure yellow)
#define C_PROP_DGREY 0x4A49
#define C_PROP_ORANGE 0xFC40
#define C_PROP_SIENNA 0xA285
#define C_PROP_LGBROWN 0xC48E  // light brown (~0xC0,0x90,0x70)

static const uint16_t P_COLOR[2] = { C_RED, C_BLUE };

// ── Board square names (must match central_bank exactly) ─────
#define NUM_SQ 40
static const char* SQ_NAMES[NUM_SQ] = {
  "GO", "Old Kent Road", "Community Chest", "Whitechapel Road",
  "Income Tax", "King's Cross Station", "The Angel Islington", "Chance",
  "Euston Road", "Pentonville Road", "Jail / Just Visiting", "Pall Mall",
  "Electric Company", "Whitehall", "Northumberland Avenue", "Marylebone Station",
  "Bow Street", "Community Chest", "Marlborough Street", "Vine Street",
  "Free Parking", "Strand", "Chance", "Fleet Street",
  "Trafalgar Square", "Fenchurch St. Station", "Leicester Square", "Coventry Street",
  "Water Works", "Piccadilly", "Go To Jail", "Regent Street",
  "Oxford Street", "Community Chest", "Bond Street", "Liverpool St. Station",
  "Chance", "Park Lane", "Super Tax", "Mayfair",
};

static const uint16_t SQ_GRP_COLORS[NUM_SQ] = {
  C_DKGRAY, C_PROP_LGREEN, C_DKGRAY, C_PROP_LGREEN, C_DKGRAY, C_DKGRAY, C_PROP_LYELLOW, C_DKGRAY,
  C_PROP_LYELLOW, C_PROP_LYELLOW, C_DKGRAY, C_PROP_DGREY, C_DKGRAY, C_PROP_DGREY, C_PROP_DGREY, C_DKGRAY,
  C_PROP_SIENNA, C_DKGRAY, C_PROP_SIENNA, C_PROP_SIENNA, C_DKGRAY, C_PROP_ORANGE, C_DKGRAY, C_PROP_ORANGE,
  C_PROP_ORANGE, C_DKGRAY, C_YELLOW, C_YELLOW, C_DKGRAY, C_YELLOW, C_DKGRAY, C_PROP_LGBROWN,
  C_PROP_LGBROWN, C_DKGRAY, C_PROP_LGBROWN, C_DKGRAY, C_DKGRAY, C_BLUE, C_DKGRAY, C_BLUE,
};

static const char* SQ_GRP_NAMES[NUM_SQ] = {
  "", "Brown", "", "Brown", "", "", "Light Blue", "",
  "Light Blue", "Light Blue", "", "Pink", "", "Pink", "Pink", "",
  "Orange", "", "Orange", "Orange", "", "Red", "", "Red",
  "Red", "", "Yellow", "Yellow", "", "Yellow", "", "Green",
  "Green", "", "Green", "", "", "Dark Blue", "", "Dark Blue",
};

// ── NFC card → square index mapping ─────────────────────────
// Assign NFC UIDs to board squares. Update UIDs after reading
// actual tags with the NFC scanner.
struct NfcMap { uint8_t uid[4]; int sq; };
static const NfcMap NFC_CARDS[] = {
  { {0xA1,0xB2,0xC3,0xD4},  0 },  // GO
  { {0x11,0x22,0x33,0x44},  1 },  // Old Kent Rd
  { {0xAA,0xBB,0xCC,0xDD},  5 },  // Kings Cross
  { {0x01,0x02,0x03,0x04},  7 },  // Chance
  { {0xDE,0xAD,0xBE,0xEF}, 10 },  // Jail
  { {0xCA,0xFE,0x00,0x01},  6 },  // Angel Islington
  { {0x12,0x34,0x56,0x78}, 11 },  // Pall Mall
  { {0xFF,0xEE,0xDD,0xCC}, 16 },  // Bow Street
};
#define NFC_MAP_N (sizeof(NFC_CARDS)/sizeof(NFC_CARDS[0]))

// Replace P1_PAY_TAG_UID with Player 1's real payment tag UID.
static const uint8_t P1_PAY_TAG_UID[7] = {0x00,0x00,0x00,0x00,0x00,0x00,0x00};
static const uint8_t P2_PAY_TAG_UID[7] = {0x04,0x19,0x53,0x75,0xCC,0x2A,0x81};

// ── Hardware objects ─────────────────────────────────────────
Adafruit_SSD1351 display(128, 128, &SPI, OLED_CS, OLED_DC, OLED_RST);
Adafruit_PN532*  nfc = nullptr;  // created in setup after Serial/OLED are alive

// ── Game State (local copy maintained from BLE messages) ─────
struct LocalState {
  // My info
  int  myBal;
  int  myPos;
  bool myTurn;
  bool inJail;

  // Other player info
  int  otherBal;
  int  otherPos;

  // Dice
  int  lastDice;       // sum of last roll (0 = not rolled yet)

  // Pending action
  enum ActionT {
    ACT_NONE, ACT_BUY, ACT_RENT, ACT_TAX,
    ACT_INFO,   // generic notification (GO, chance, chest, etc.)
    ACT_WIN, ACT_LOSE
  } action;
  char actionTitle[24];
  char actionDesc[48];
  int  actionAmt;
  int  proxyPayFor;    // other player number this reader can confirm by NFC tag

  // Auction
  bool auctionActive;
  int  auctionSq;         // square index being auctioned
  int  auctionStartPrice; // starting price (list price)
  int  auctionBid;        // current highest bid
  int  auctionBidder;     // player number of highest bidder (1-based, 0=none)
  int  myBidAmt;          // bid amount player is composing (UP/DOWN to adjust)
  uint32_t auctionStartMs; // millis() when auction started (for countdown)

  // Connection
  bool bleConnected;
  bool gameStarted;
  bool gameOver;
} S;
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

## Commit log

2026-04-20 Add FSR and RFID sensor streaming code with READMEs
    - FSR test: streams analog FSR readings via Serial at 115200 baud
    - RFID test: streams dual MFRC522 card UIDs via Serial at 115200 baud
    - Each project includes platformio.ini and setup instructions in README
2026-04-24 magnetic add
2026-04-27 hall readme add
2026-05-09 Add monopoly_final: central display + player device test code
    - central_display_test: CrowPanel ESP32-S3 5" LovyanGFX driver, dice animation,
    touch input, STC8H1K28 backlight/buzzer via I2C (bus_shared fix, double-buffer)
    - player_device_test: OLED + PN532 RFID player device
    - SYSTEM_ARCHITECTURE.md: full system design doc
    - crowpanel_5inch_v11_pinout.md: pin reference for V1.1 board
    - .gitignore: exclude CrowPanel example repo, PDFs, PlatformIO build artifacts
    [main.cpp, player_device_test.ino]
2026-06-08 Add final Monopoly game code: central bank + player card
    - central_bank: CrowPanel 5" ESP32-S3 game master with full Monopoly
    rules, dice animation, property auctions, BLE server, touch UI
    - player_card: XIAO ESP32S3 handheld with SSD1351 OLED, PN532 NFC,
    5-button input, BLE client for 2-player game
    - README with system architecture, wiring, BLE protocol, build instructions
    - Updated player_device_test with latest fixes
    [main.cpp]
2026-06-08 project finished
    [.step, bottom.stl, button_cap.stl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]
